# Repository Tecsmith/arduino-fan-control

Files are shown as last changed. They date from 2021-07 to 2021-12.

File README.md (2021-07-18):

# Qwiic Fan Control Module

- This is the **EAGLE** *PCB* design project
- For the **Arduino** *code* library please see [Tecsmith](https://github.com/Tecsmith)/[Tecsmith_AMC6821](https://github.com/Tecsmith/Tecsmith_AMC6821)

AMC6821 based Fan Control Module with Qwiic connectors for integration into 3.3V MCU projects.

| &#8505; | URL |
|---:|-----|
| Project website | [tecsmith.github.io/arduino-fan-control](https://tecsmith.github.io/arduino-fan-control/) |
| Quick link | [`c1k.it/amc6`](http://c1k.it/amc6) |
| Github EAGLE-CAD Source | https://github.com/Tecsmith/arduino-fan-control/tree/master/EAGLE |
| Github PlatformIO Source | https://github.com/Tecsmith/arduino-fan-control/tree/master/PlatformIO |

## About

Thermal control is often arbitrarily implemented in electronics projects – adoption of fans for heat management is often done without consideration for power consumption or acoustic noise.

Leveraging the Texas Instruments AMC6821 chip, this module adds an intelligent temperature monitor and pulse-width modulation (PWM) fan controller to a fan. It is designed for noise-sensitive or power-sensitive applications that require active system cooling. Using a PWM signal, this device simultaneously drives a fan, monitors remote sensor diode temperatures, and measures/controls the fan speed so that it operates with minimal acoustic noise at the lowest possible speed.

This project is an Open Source Hardware (OSH) project and is based on [SparkFun's Qwiic](https://www.sparkfun.com/qwiic) I<sup>2</sup>C connectors and can be integrated into many 3.3V based MCU's.

## AMC6821
### Intelligent temperature monitor and pulse-width modulation fan controller

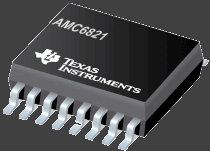
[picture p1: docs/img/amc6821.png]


The AMC6821 is an intelligent temperature monitor and pulse-width modulation (PWM) fan controller. It is designed for noise-sensitive or power-sensitive applications that require active system cooling. Using a low-frequency or a high-frequency PWM signal, this device can simultaneously drive a fan, monitor remote sensor diode temperatures, and measure and control the fan speed so that it operates with minimal acoustic noise at the lowest possible speed.

The AMC6821 has four fan control modes: *Auto Temperature-Fan* mode, *Software-RPM* mode, *Software-DCY* mode, and *Maximum fast-speed calculated control* mode.  Each mode controls the fan speed by changing the duty cycle of a PWM output.

- <u>**Auto Temperature-Fan**</u> mode is an intelligent, closed-loop control that optimizes fan speed according to user-defined parameters. This mode allows the AMC6821 to run as a stand-alone device without CPU intervention; the fan can continue to be controlled (based on temperature measurements) even if the CPU or system locks up.

- <u>**Software-RPM**</u> mode is a second closed-loop control. In this mode, the AMC6821 adjusts the PWM output to maintain a consistent fan speed at a user-specified target value; that is, the device functions as a fan speed regulator. Software-RPM mode can also be used to allow the AMC6821 to operate as a stand-alone device.

- <u>**Software-DCY**</u> mode is the third mode and is open-loop. In Software-DCY mode, the PWM duty cycle is set directly by the value written to the device.

- <u>**Maximum fast-speed calculated control**</u> mode.

The AMC6821 also has a programmable `SMBALERT` output to indicate error conditions and a dedicated `FAN-FAULT` output to indicate fan failure. The `THERM` pin is a fail-safe output for over-temperature conditions that can be used to throttle a CPU clock. Additionally, the `OVR` pin indicates the over-temperature limit as well. All of the alarm thresholds are set through the device registers. The AMC6821 is available in a QSOP-16 package.

## Project Features

- Designed to be an inline series add-on for existing fan implementations.
- Can be powered from 12V and/or 5V power sources. _(Dependant on Fan required operational voltage.)_
- Support most fan types, 5V~ and 12V
  * 4-wire _(Tachometer + PWM)_
  * 3-wire _(Tachometer Sensor)~_
  * 3-wire _(Locked Rotor Sensor)~_
  * 2-wire~
- Can be run as standalone module.
- Can be chained for up to 9 fans, depending on I<sup>2</sup>C addresses set at A0 and A1 pins.
- Both Qwiic and generic I<sup>2</sup>C headers for communication with 3.3V based MCU boards.

> *~ = with add-on MOSFET*

----------
<p align="center" style="color:#069">&#9733;</p>

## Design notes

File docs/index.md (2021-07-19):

# Qwiic Fan Control Module

AMC6821 based Fan Control Module with Qwiic connectors for integration into 3.3V MCU projects.

GitHub repository at [Tecsmith/arduino-fan-control](https://github.com/Tecsmith/arduino-fan-control)

## Features / Specifications

This project contains 2 PCB boards:
* AMC6821 Breakout Board, *allowing intergration via I<sup>2</sup>C to:*
  * [ESP-01 dev board](https://github.com/Tecsmith/arduino-esp-01-dev-board),
  * [Pro-Micro screw terminal board](https://github.com/Tecsmith/arduino-pro-micro-screw-terminal),
  * [Wemos D1 Mini screw terminal board](https://github.com/Tecsmith/arduino-wemos-d1-screw-terminal), and
  * Many other MCU boards from your favorite suppliers, like:
    * [SparkFun](https://www.sparkfun.com/search/results?term=qwiic) Qwiic *[Niwot, Colorado, USA]*
    * [AdaFruit](https://www.adafruit.com/?q=STEMMA+QT) STEMMA QT *[NYC, New York, USA]*
    * [Smart Prototyping](https://www.smart-prototyping.com/index.php?route=product/search&search=qwiic) *[Hong Kong & Shenzhen, China]*
    * [Core Electronics](https://core-electronics.com.au/search/?q=piicodev) PiicoDev *[Hunter Valley, Australia]*
* Fan Host Board, *supporting:*
  * The above [AMC6821 Breakout Board](#), and
  * the [Adafruit EMC2101 Breakout Board](https://www.adafruit.com/product/4808)

### AMC6821 Breakout Board

- Host for [Texas Instruments AMC6821](https://www.ti.com/lit/gpn/amc6821) Intelligent Temperature Monitor and PWM Fan Controller
- Integrates into other 3.3V based MCUs (via Qwiic / STEMMA QT connectors) 
- I<sup>2</sup>C breakout pins (SCL, SDA, 3V3, GND)
  * on board 2.2KΩ pullups, disable by cutting jumpers
- AMC6821 breakout pins (PWM, TACH, <u>FAN-FAULT</u> and <u>SMBALERT</u>. <u>OVR</u> and <u>THERM</u> are also available.)
- Power LED (green)
- 2x Qwiic connector (works with SparkFun's [Qwiic Connect System](https://www.sparkfun.com/qwiic), or Adafruit's [STEMMA QT](https://www.adafruit.com/?q=stemma+qt))
- Supports 2x PWM Modes (via Jumper)
- Supports 9x I<sup>2</sup>C Addresses (via Jumper)
- Includes an on board Temperature sensor
  * can be cut out for remote installation (use rotary cutter along break line)

### Fan Host Board

- Powered from 12V + 5V power supply
  * or just 12V with optional 12V-to-5V ("7805" IC or Pololu 5V Step-Down) regulator
  * or just 5V for 5V fans
- Supports most industry FAN types
  - Molex 4-wire `KK-254-47053-1000` connector
    * 12V PWM, 4-wire, with Tachometer & PWM control
    * 12V, 3-wire, with Tachometer
    * 12V, 3-wire, with Rotor-Lock
    * 12V, 2-wire
  - JST 2-wire connector
    * 5V, 2-wire

----------

## On board jumpers

### AMC6821 Breakout Board

#### JP0 & JP1 - _{A0 & A1}_ - I<sup>2</sup>C Address Selector

| A0 / JP0 | A1 / JP1 |  7-bit  | Hex  | Address |
|:---:|:---:|:---:|:---:|:---|
| GND | GND | 0011000 | `0x18` | 24 *&#9734;* |
| 3V3 | GND | 0011001 | `0x19` | 25 |
|  *N/C~*  | GND | 0011010 | `0x1A` | 26 |
| GND | 3V3 | 1001100 | `0x4C` | 76 |
| 3V3 | 3V3 | 1001101 | `0x4D` | 77 |
|  *N/C~*  | 3V3 | 1001110 | `0x4E` | 78 |
| GND |  *N/C~*  | 0101100 | `0x2C` | 44 |
| 3V3 |  *N/C~*  | 0101001 | `0x2D` | 45 |
|  *N/C~*  |  *N/C~*  | 0101110 | `0x2E` | 46 |

<sub>&#9734; = default setting</sub><br>
<sub>*~* = Not connected</sub>

#### JP2 - _{PWM/M}_ - PWM Mode *(for Frequency selection)*

|  JP2 | PWM Mode |
|:---:|:---|
|  GND | High Frequency range, 1kHz to 40kHz *&#9734; <sup>(25kHz)</sup>* |
|  3V3 | Low Frequency range, 10Hz to 94Hz |

- *Actual PWM Frequency depends on Fan Characteristics Register, bits 3-5*

#### JP3 - _{I2C P/U}_ - I<sup>2</sup>C Pullups Enable

| JP3 | I<sup>2</sup>C Pullups |
|:---:|:---|
| Both connected | 2.2KΩ pull-ups *&#9734;* |
| Both cut | No pull-ups |

- *I<sup>2</sup>C Bus should have at least one set of pullups.*

#### LED (JP4) - Power LED

| LED (JP4) | LED function |
|:---:|:---|
| Tied | LED active to show power state *&#9734;* |
| Cut | Power LED disabled |

### Fan Host Board

The AMC6821 fan controllers has a voltage range on the TACH and PWM pins of -0.3Vdc to 6.5Vdc.  

&#9888; **Do not connect 12Vdc lines to the IC pins.**

#### TACH Control cluster

For the AMC6821 *(and also the EMC2101)* the TACH *(tachometer)* reading is done on the TACH or SENSE pin of the fan.  Most fans operate by grounding this pin once or twice per revolution - thus requiring a pull-up resistor.

##### 12V Fans

For 12V Fans a voltage divider array of resistors *(made up of R2, R3 & R4)* ensure that the TACH pin on the IC is near the 3V range, and the SENS pin on the fan is in the 7V range.

<figure>
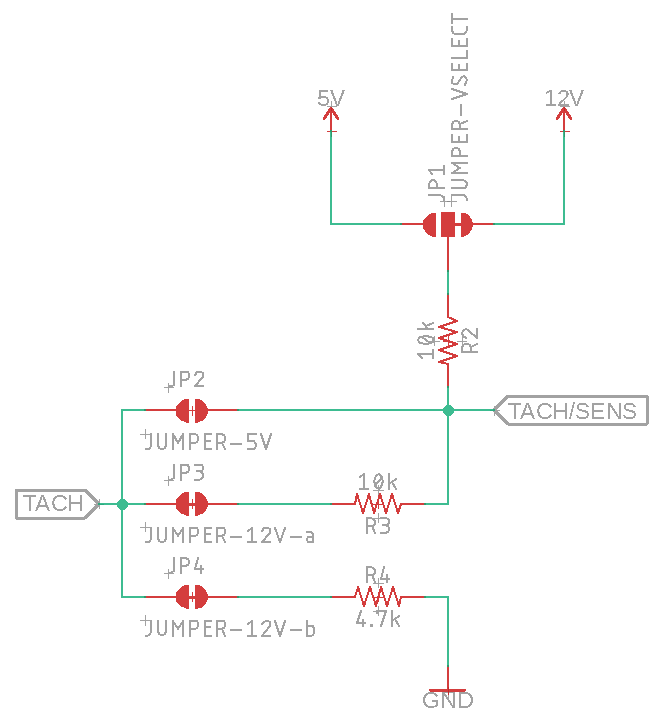
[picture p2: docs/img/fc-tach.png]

<figcaption>TACH circuit with J1 (to 12V), J3 & J4 providing a voltage divider</figcaption>
</figure>

##### 5V Fans

For 5V Fans only a pull-up resistor is required *(R2)*.
* JP2 must be soldered together,
* JP1 must have the 12V trace cut, and the 5V side soldered to center, *and*
* JP3 & JP4 must both be cut

##### TACH Control Cluster

In summary:

| Jumper  | for 12V Fans | for 5V fans |
|:---:|:---:|:---:|
| JP1 | bound to 12V &#9734; | bound to 5V |
| JP2 | cut &#9734; | bound |
| JP3 | bound &#9734; | cut |
| JP4 | bound &#9734; | cut |

#### PWM Control cluster

Fan speed control is managed by the PWM signal from the AMC6821 *(and also the EMC2101)*.  This pin should always be pulled up to the reference voltage of the IC *(not the fan!)*.

> &#8505; &nbsp; The board does ***not*** provide a 3.3Vdc line.  This is sourced from the daughter board GND pin.

<figure>
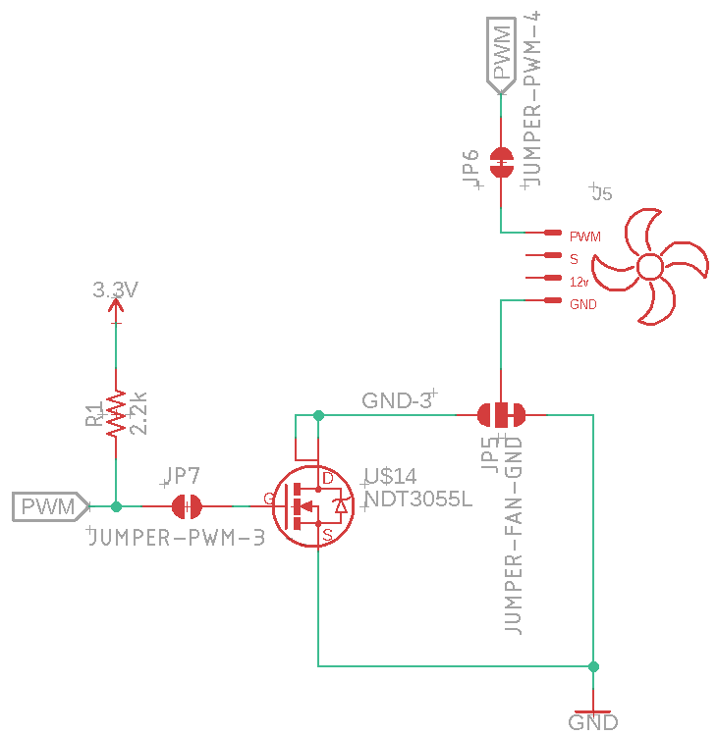
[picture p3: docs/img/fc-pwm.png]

<figcaption>An N-Channel MOSFET provides PWM fan speed control for 3-, or 2- pin fans</figcaption>
</figure>

##### For 4-pin Fans

4-pin fans have a the fourth pin providing PWM signal to the fan internals.  This is pin is enabled by default via the bound trace on JP6.

##### For 2-, and 3-pin Fans

2-, and 3-pin fans do not regulate speed internally, so a N-Channel MOSFET is used to provide low-frequency PWM control to the Ground side of the fan *(avoiding the problems experienced in linear control at lower voltages)*.

To activate the MOSFET driver JP7 must be bound *(and JP6 cut to prevent PWM to fan signal)*.

##### PWM Control cluster

In summary:

| Jumper  | for 4-pin Fans | for 5V fans |
|:---:|:---:|:---:|
| JP5 | bound "to GND" &#9734; | bound "to MFET" |
| JP6 | bound &#9734; | cut |
| JP7 | cut &#9734; | bound |

----------

## Manufacturing

> *I have not sent these for production yet. Want to make sure the thing works on a proto-board first. I'll update this page when done.*

### AMC6821 Breakout Board

* Schematic print:              [`amc6821-breakout-v3.0.pdf`](amc6821-breakout-v3.0.pdf)
* Schematic source (EAGLE CAD): [`amc6821-breakout-v3.0.sch`](https://github.com/Tecsmith/arduino-fan-control/blob/master/EAGLE/amc6821-breakout-v3.0.sch)
* PCB design (EAGLE CAD):       [`amc6821-breakout-v3.0.brd`](https://github.com/Tecsmith/arduino-fan-control/blob/master/EAGLE/amc6821-breakout-v3.0.brd)

--

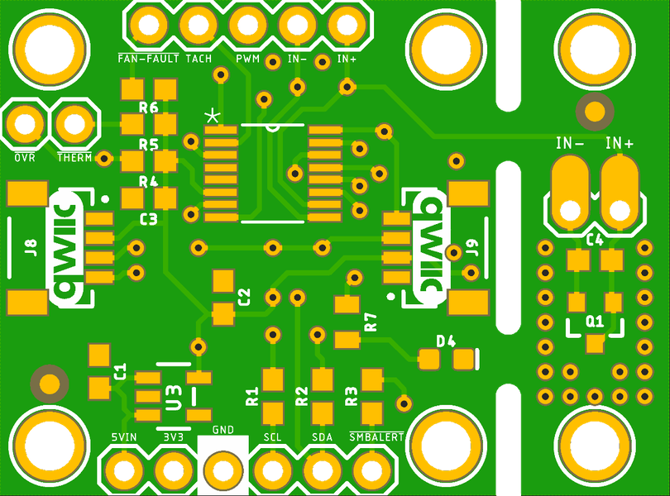
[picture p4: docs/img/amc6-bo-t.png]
<figure><figcaption>Top</figcaption></figure>
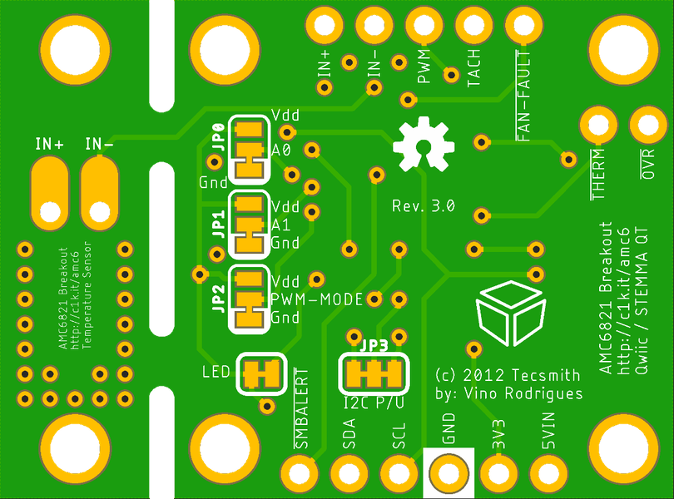
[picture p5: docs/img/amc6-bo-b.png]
<figure><figcaption>Bottom</figcaption></figure>

### Fan Host Board

* Schematic print:              [`fan-host-board-v1.0`](fan-host-board-v1.0.pdf)
* Schematic source (EAGLE CAD): [`fan-host-board-v1.0.sch`](https://github.com/Tecsmith/arduino-fan-control/blob/master/EAGLE/fan-host-board-v1.0.sch)
* PCB design (EAGLE CAD):       [`fan-host-board-v1.0.brd`](https://github.com/Tecsmith/arduino-fan-control/blob/master/EAGLE/fan-host-board-v1.0.brd)

--

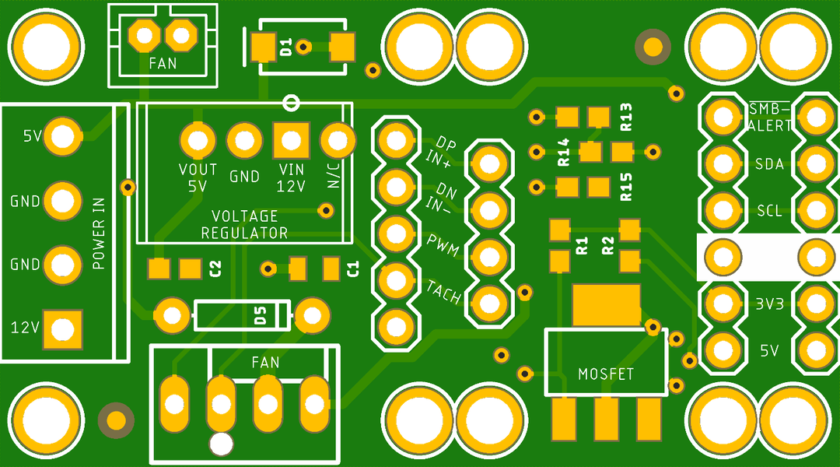
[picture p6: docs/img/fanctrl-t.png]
<figure><figcaption>Top</figcaption></figure>
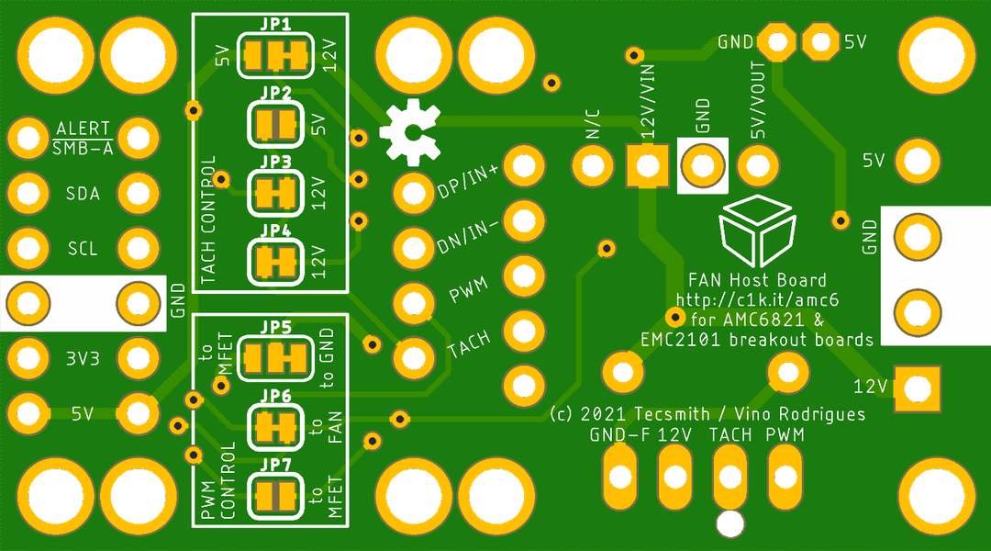
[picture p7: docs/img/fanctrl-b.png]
<figure><figcaption>Bottom</figcaption></figure>

----------

## Source Code

Currently under development ... refer to:

* PlatfromIO examples: [Tecsmith/arduino-fan-control/PlatformIO](https://github.com/Tecsmith/arduino-fan-control/tree/master/PlatformIO)
* AMC6821 Library: [Tecsmith/Tecsmith_AMC6821](https://github.com/Tecsmith/Tecsmith_AMC6821)

----------
<p align="center" style="color:#069">★</p>

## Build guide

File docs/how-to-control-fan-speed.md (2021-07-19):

# Why and How to Control Fan Speed for Cooling Electronic Equipment
***by Mary Burke***<br>
*February 2004*

> Original publication at [AnalogDialogue / analog.com](https://www.analog.com/en/analog-dialogue/articles/how-to-control-fan-speed.html)<br>
> [Download PDF](https://www.analog.com/media/en/analog-dialogue/volume-38/number-1/articles/how-to-control-fan-speed.pdf)

## Introduction

Interest has been growing in integrated circuits for controlling the speed of cooling fans in personal computers and other electronic equipment. Compact electrical fans are cheap and have been used for cooling electronic equipment for more than half a century. However, in recent years, the technology of using these fans has evolved significantly. This article will describe how and why this evolution has taken place and will suggest some useful approaches for the designer.

## Heat Generation and Removal

The trend in electronics, particularly consumer electronics, is towards smaller products with enhanced combinations of features. Consequently, lots of electronic components are being shoehorned into very small form factors. An obvious example is the notebook PC. Thin and “Lite,” notebook PCs have shrunk significantly, yet their processing power has been maintained or increased. Other examples of this trend include projection systems and set-top boxes. What these systems all have in common, besides significantly smaller—and still decreasing—size, is that the amount of heat they must dissipate does not decrease; often it increases! In the notebook PC, much of the heat is generated by the processor; in the projector, most of the heat is generated by the light source. This heat needs to be removed quietly and efficiently.

The quietest way to remove heat is with passive components such as heat sinks and heat pipes. However, these have proved insufficient in many popular consumer electronics products—and they are also somewhat expensive. A good alternative is active cooling, introducing a fan into the system to generate airflow around the chassis and the heat-generating components, efficiently removing heat from the system. A fan is a source of noise, however. It is also an additional source of power consumption in the system—a very important consideration if power is to be supplied by a battery. The fan is also one more mechanical component in the system, not an ideal solution from a reliability standpoint.

*Speed control* — one way to answer some of these objections to the use of a fan—can have these advantages:

1. running a fan slower reduces the noise it emits,
2. running a fan slower can reduce the power it consumes,
3. running a fan slower increases its reliability and lifetime.

There are many different types of fans and ways of controlling them. We will discuss here various fan types and the advantages and disadvantages of control methods in use today. One way to classify fans is as:

1. 2-wire fans
2. 3-wire fans 
3. 4-wire fans.

The methods of fan control to be discussed here include:

1. no fan control
2. on/off control
3. linear (continuous dc) control
4. low-frequency pulse-width modulation (PWM)
5. high-frequency fan control.

## Fan Types

A 2-wire fan has power and ground terminals. A 3-wire fan has power, ground, and a tachometric (“tach”) output, which provides a signal with frequency proportional to speed. A 4-wire fan has power, ground, a tach output, and a PWM-drive input. PWM, in brief, uses the relative width of pulses in a train of on-off pulses to adjust the level of power applied to the motor.

A 2-wire fan is controlled by adjusting either the dc voltage or pulse width in low-frequency PWM. However, with only two wires, a tach signal is not readily available. This means that there is no indication as to how fast the fan is running—or indeed, if it is running at all. This form of speed control is open-loop.

A 3-wire fan can be controlled using the same kind of drive as for 2-wire fans—variable dc or low-frequency PWM. The difference between 2-wire fans and 3-wire fans is the availability of feedback from the fan for closed-loop speed control. The tach signal indicates whether the fan is running and its rate of speed.

The tach signal, when driven by a dc voltage, has a square-wave output closely resembling the “ideal tach” in Figure 1. It is always valid, since power is continuously applied to the fan. With low- frequency PWM, however, the tach signal is valid only when power is applied to the fan—that is, during the on phase of the pulse. When the PWM drive is switched to the off phase, the fan’s internal tach signal-generation circuitry is also off. Because the tach output is typically from an open drain, it will float high when the PWM drive is off, as shown in Figure 1. Thus, while the ideal tach is representative of the actual speed of the fan, the PWM drive in effect “chops” the tach signal output and may produce erroneous readings.

<figure>
  
  <figcaption>Figure 1. Tachometer-output waveform in 3-wire fans—ideal, and under PWM control.</figcaption>
</figure>

In order to be sure of a correct fan speed reading under PWM control, it is necessary to periodically switch the fan on long enough to get a complete tach cycle. This feature is implemented in a number of Analog Devices fan controllers, such as the ADM1031 and the ADT7460.

In addition to the power, ground, and tach signal, 4-wire fans have a PWM input, which is used to control the speed of the fan. Instead of switching the power to the entire fan on and off, only the power to the drive coils is switched, making the tach information available continuously. Switching the coils on and off generates some commutation noise. Driving the coils at rates greater than 20 kHz moves the noise outside of the audible range, so typical PWM fan-drive signals use a rather high frequency (>20 kHz). Another advantage of 4-wire fans is that the fan speed can be controlled at speeds as low as 10% of the fan’s full speed. Figure 2 shows the differences between 3-wire and 4-wire fan circuits.

<figure>
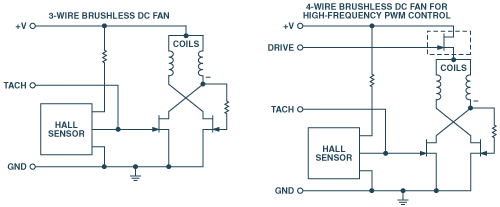
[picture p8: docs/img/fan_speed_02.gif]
  
  <figcaption>Figure 2. 3- and 4-wire fans.</figcaption>
</figure>

## Fan Control

No control: The simplest method of fan control is not to use any at all; just run a fan of appropriate capacity at full speed 100% of the time. The main advantages of this are guaranteed fail-safe cooling and a very simple external circuit. However, because the fan is always switched on, its lifetime is reduced and it uses a constant amount of power—even when cooling is not needed. Also, its incessant noise is likely to be annoying.

On/off control: The next simplest method of fan control is thermostatic, or on/off control. This method is also very easy to implement. The fan is switched on only when cooling is needed, and it is switched off for the remainder of the time. The user needs to set the conditions under which cooling is needed—typically when the temperature exceeds a preset threshold.

The Analog Devices ADM1032 is an ideal sensor for on/off fan control using a temperature setpoint. It has a comparator that produces a THERM output—one that is normally high but switches low when the temperature exceeds a programmable threshold. It automatically switches back to high when the temperature drops a preset amount below the THERM Limit. The advantage of this programmable hysteresis is that the fan does not continually switch on/off when the temperature is close to the threshold. Figure 3 is an example of a circuit using the ADM1032.

<figure>
  
  <figcaption>Figure 3. Example of an on/off control circuit.</figcaption>
</figure>

The disadvantage of on/off control is that it is very limited. When a fan is switched on, it immediately spins up to its full speed in an audible and annoying manner. Because humans soon become somewhat accustomed to the sound of the fan, its switching off is also very noticeable. (It can be compared to the refrigerator in your kitchen. You didn’t notice the noise it was making until it switched off.) So from an acoustic perspective, on/off control is far from optimal.

**Linear control:** At the next level of fan control, linear control, the voltage applied to the fan is variable. For lower speed (less cooling and quieter operation) the voltage is decreased, and for higher speed it is increased. The relationship has limitations. Consider, for example, a 12-V fan (rated maximum voltage). Such a fan may require at least 7 V to start spinning. When it does start spinning, it will probably spin at about half its full speed with 7 V applied. Because of the need to overcome inertia, the voltage required to start a fan is higher than the voltage required to keep it spinning. So as the voltage applied to the fan is reduced, it may spin at slower speeds until, say, 4 V, at which point it will stall. These values will differ, from manufacturer to manufacturer, from model to model, and even from fan to fan.

The Analog Devices ADM1028 linear fan-control IC has a programmable output and just about every feature that might be needed in fan control, including the ability to interface accurately to the temperature-sensing diode provided on chips, such as microprocessors, that account for most of the dissipation in a system. (The purpose of the diode is to provide a rapid indication of critical junction temperatures, avoiding all the thermal lags inherent in a system. It permits immediate initiation of cooling, based on a rise in chip temperature.) In order to keep the power used by the ADM1028 at a minimum, it operates on supply voltages from 3.0 V to 5.5 V, with +2.5-V full scale output.

5-V fans allow only a limited range of speed control, since their start-up voltage is close to their 5-V full speed level. But the ADM1028 can be used with 12-V fans by employing a simple step-up booster amplifier with a circuit such as that shown in Figure 4.

<figure>
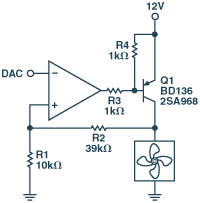
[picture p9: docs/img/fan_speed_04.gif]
  
  <figcaption>Figure 4. Boost circuit for driving a 12-V fan, using the output from the linear fan-control ADM1028’s DAC.</figcaption>
</figure>

The principal advantage of linear control is that it is quiet. However, as we have noted, the speed-control range is limited. For example, a 12-V fan with a control voltage range from 7 V to 12 V could be running at half speed at 7 V. The situation is even worse with a 5-V fan. Typically, 5-V fans will require that 3.5 V or 4 V be applied to get them started, but at that voltage they will be running at close to full speed, with a very limited range of speed control. But running at 12 V, using circuits such as that shown in Figure 4, is far from optimum from an efficiency perspective. That is because the boost transistor dissipates a relatively large amount of power (when the fan is operating at 8 V, the 4-V drop across the transistor is not very efficient). The external circuit required is also relatively expensive.

**PWM Control:** The prevalent method currently used for controlling fan speed in PCs is low-frequency PWM control. In this approach, the voltage applied to the fan is always either zero or full-scale—avoiding the problems experienced in linear control at lower voltages. Figure 5 shows a typical drive circuit used with PWM output from the ADT7460 thermal voltage controller.

<figure>
  
  <figcaption>Figure 5. A low-frequency PWM fan-drive circuit.</figcaption>
</figure>

The principal advantage of this drive method is that it is simple, inexpensive, and very efficient, since the fan is either fully on or fully off.

A disadvantage is that the tach information is chopped by the PWM drive signal, since power is not always applied to the fan. The tach information can be retrieved using a technique called pulse stretching—switching the fan on long enough to gather the tach information (with a possible increase of audible noise). Figure 6 shows a case of pulse stretching.

<figure>
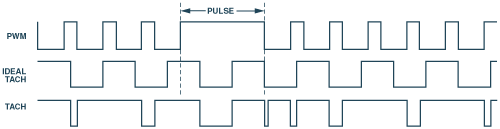
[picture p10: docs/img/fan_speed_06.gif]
  
  <figcaption>Figure 6. Pulse stretching to gather tach information.</figcaption>
</figure>

Another disadvantage of low-frequency PWM is commutation noise. With the fan coils continuously switched on and off, audible noise may be present. To deal with this noise, the newest Analog Devices fan controllers are designed to drive the fan at a frequency of 22.5 kHz, which is outside the audible range. The external control circuit is simpler with high-frequency PWM, but it can only be used with 4-wire fans. Although these fans are relatively new to the market, they are rapidly becoming more popular. Figure 7 depicts the circuit used for high-frequency PWM.

<figure>
  
  <figcaption>Figure 7. Circuit for driving a fan with high-frequency PWM.</figcaption>
</figure>

The PWM signal drives the fan directly; the drive FET is integrated inside the fan. Reducing the external component count, this approach makes the external circuit much simpler. Since the PWM drive signal is applied directly to the coils of the fan, the fan’s electronics are always powered on, and the tach signal is always available. This eliminates the need for pulse stretching—and the noise it can produce. The commutation noise is also eliminated, or reduced significantly, since the coils are being switched with a frequency outside the audible range.

## Summary

From the standpoints of acoustic noise, reliability, and power efficiency, the most preferable method of fan control is the use of high-frequency (>20 kHz) PWM drive.

Besides eliminating the need for noisy pulse stretching and the commutation noise associated with low-frequency PWM, it has a much wider control range than linear control. With high- frequency PWM, the fan can be run at speeds as low as 10% of full speed, while the same fan may only run at a minimum of 50% of full speed using linear control. It is more energy efficient, because the fan is always either fully on or fully off. (With the FET either off or in saturation, its dissipation is very low, eliminating the significant losses in the transistor in the linear case.) It is quieter than always-on or on/off control, since the fan can run at lower speeds—that can be varied gradually. Finally, running the fan slower also improves its lifetime, increasing system reliability.

| Control Method | Advantages | Disadvantages |
|:---:|:---|:---|
| On/Off | Inexpensive | Worst acoustic performance—fan is always running. |
| Linear | Most quiet | Expensive circuit <br> Inefficient—loss of power in the amplifier circuit |
| Low-Frequency PWM | Efficient <br> Wide speed-control range when measuring speed | Fan commutation noise <br> Pulse stretching required |
| High-Frequency PWM | Efficient <br> Good acoustics, almost as good as linear. <br> Inexpensive external circuit <br> Wide speed-control range |  Must use 4-wire fans |

<p align="center" style="color:#069">★</p>

> &copy; Analog Dialogue 38-02, February (2004), accessed from https://www.analog.com/en/analog-dialogue/articles/how-to-control-fan-speed.html, accessed 19 July 202<br>
> PDF available from https://www.analog.com/media/en/analog-dialogue/volume-38/number-1/articles/how-to-control-fan-speed.pdf

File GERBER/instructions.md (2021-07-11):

Instructions
============

See this Tutorial: https://www.youtube.com/watch?v=y3GviDr0o1s

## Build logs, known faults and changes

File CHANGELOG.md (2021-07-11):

# Changelog
All notable changes to this project will be documented in this file.

The format is based on [Keep a Changelog](https://keepachangelog.com/en/1.0.0/),
and this project adheres to [Semantic Versioning](https://semver.org/spec/v2.0.0.html).

[[[[[ **This project is in WIP state.** ]]]]]

## [Unreleased]

### Added

- Rebuild of PlatformIO examples

### Removed

- Sub projects removed (and added to their own GitHub projects)
  * [arduino-esp-01-dev-board](https://github.com/Tecsmith/arduino-esp-01-dev-board)
  * [arduino-pro-micro-screw-terminal](https://github.com/Tecsmith/arduino-pro-micro-screw-terminal)
  * [arduino-wemos-d1-screw-terminal](https://github.com/Tecsmith/arduino-wemos-d1-screw-terminal)
  * arduino-emc2101 *(deleted)*

### Changed

- Arduino examples renamed.  These will stay, but not be maintained or added on as PlatformIO is the preferred environment.

## [2.3.0] - 2020-12-17

### Added

- Initial AMC6820 and SMBus libraries
- WIP PlatformIO code to test IC integration

### Changed

- Realized that JP2 = A0 and JP3 = A1 could lead to confusion, renamed all JP's (with J0 = A0 & J1 = A1)
- Created expanded solder pads on Optional Temp. Sensor to allow for horizontal cable soldering.
- Moved Qwiic connectors up by 25mil to allow better clearance of mounting screws.
- Issue identified with JLCPCB validation
    + C7 (Optional Temp. Sensor capacitor) was the incorrect footprint, changed from 0402 to 0805.  This is a breaking error, however, since sensor is optional will not impact development of firmware.
    + Q2, Q3, Q4 (Red LED inversion transistors) were the incorrect footprint.  Non-breaking.  Changed to SOT23-3. Moved the route airwires to accommodate.

## [2.2.0] - 2020-12-05

### Changed

- Fix for the Qwiic connector being oriented the wrong way

## [2.1.0] - ?

- Unreleased

## [2.0.0] - 2020-11-02

### Added
- Initial release (and first production run with [JLCPCB](https://jlcpcb.com/))

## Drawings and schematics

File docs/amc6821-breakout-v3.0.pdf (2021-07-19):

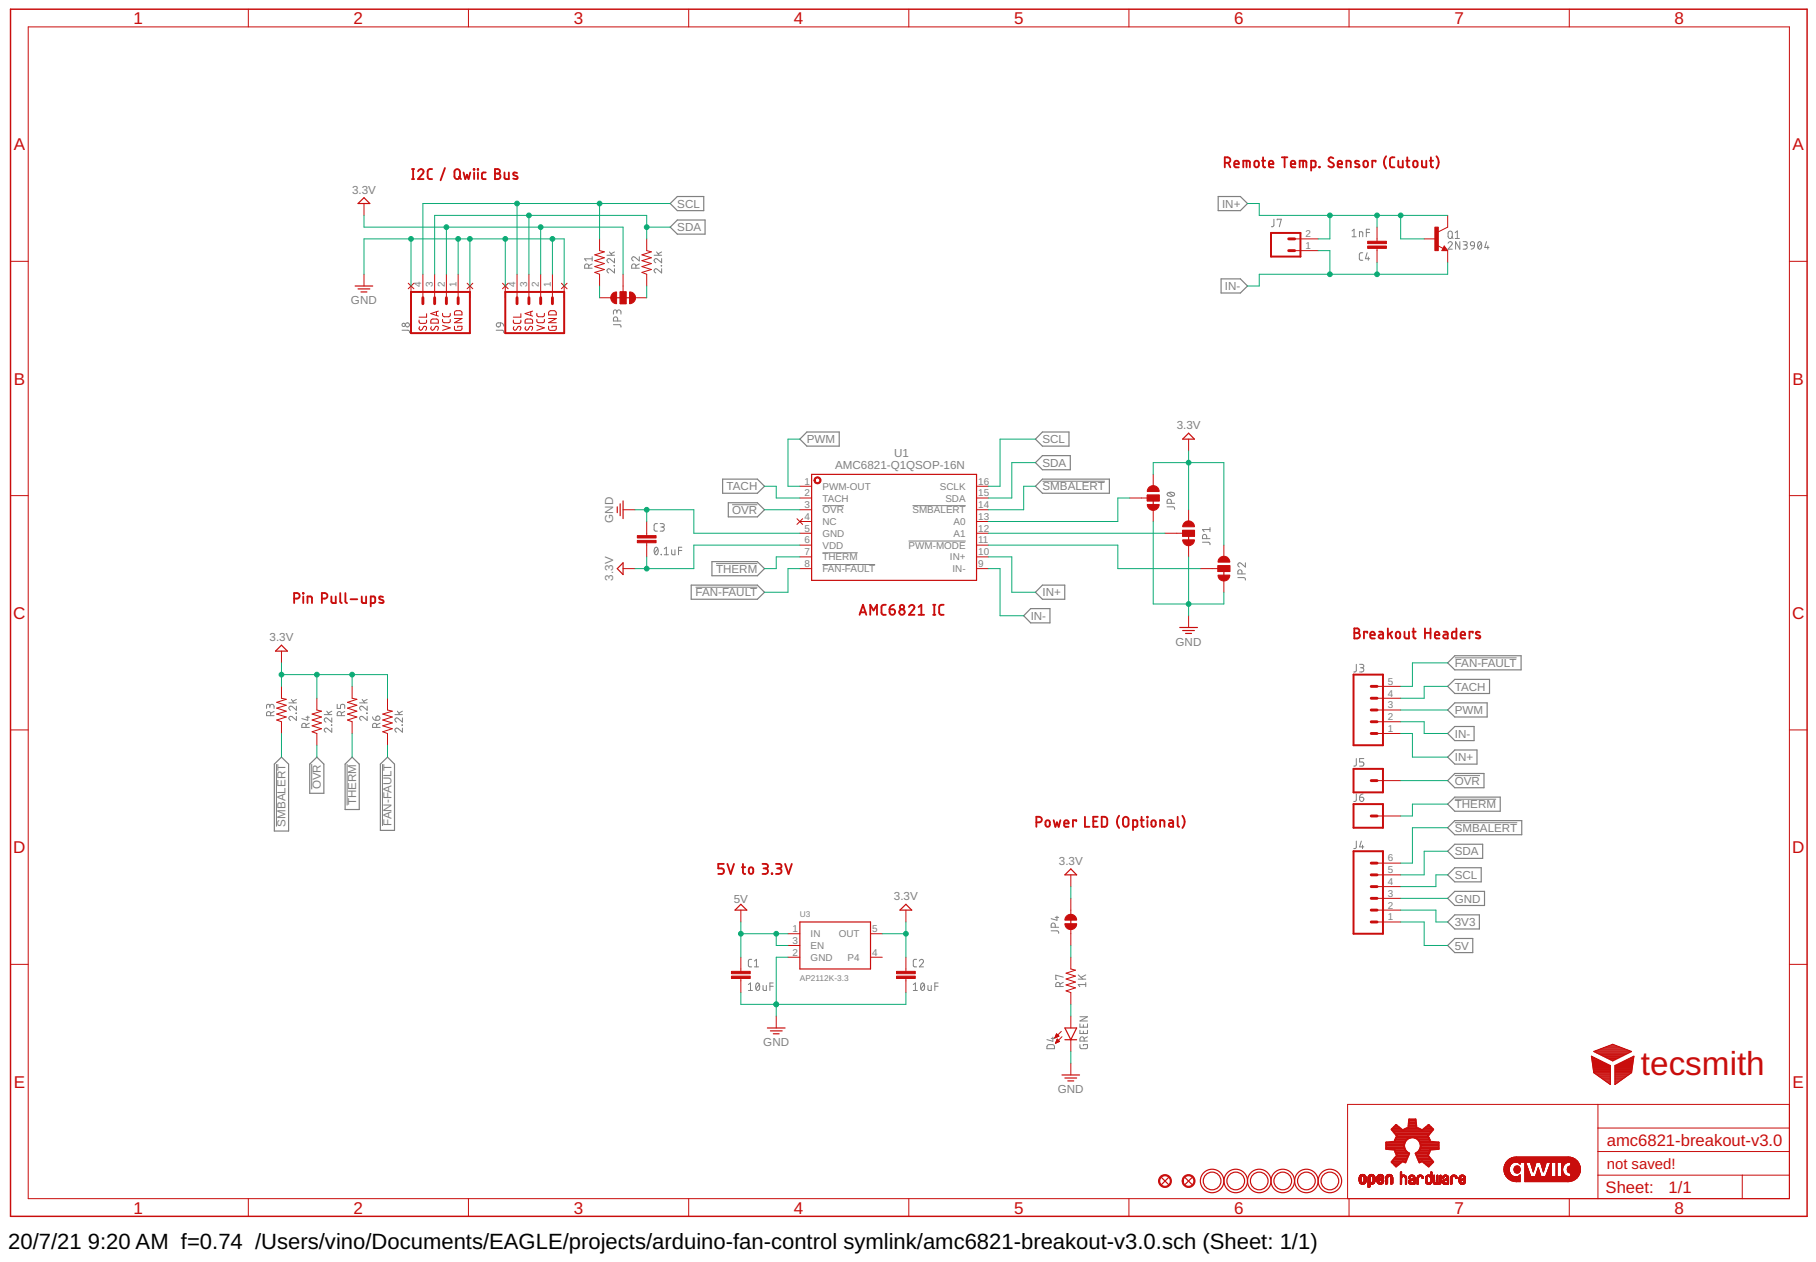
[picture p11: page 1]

20/7/21 9:20 AM f=0.74 /Users/vino/Documents/EAGLE/projects/arduino-fan-control symlink/amc6821-breakout-v3.0.sch (Sheet: 1/1)

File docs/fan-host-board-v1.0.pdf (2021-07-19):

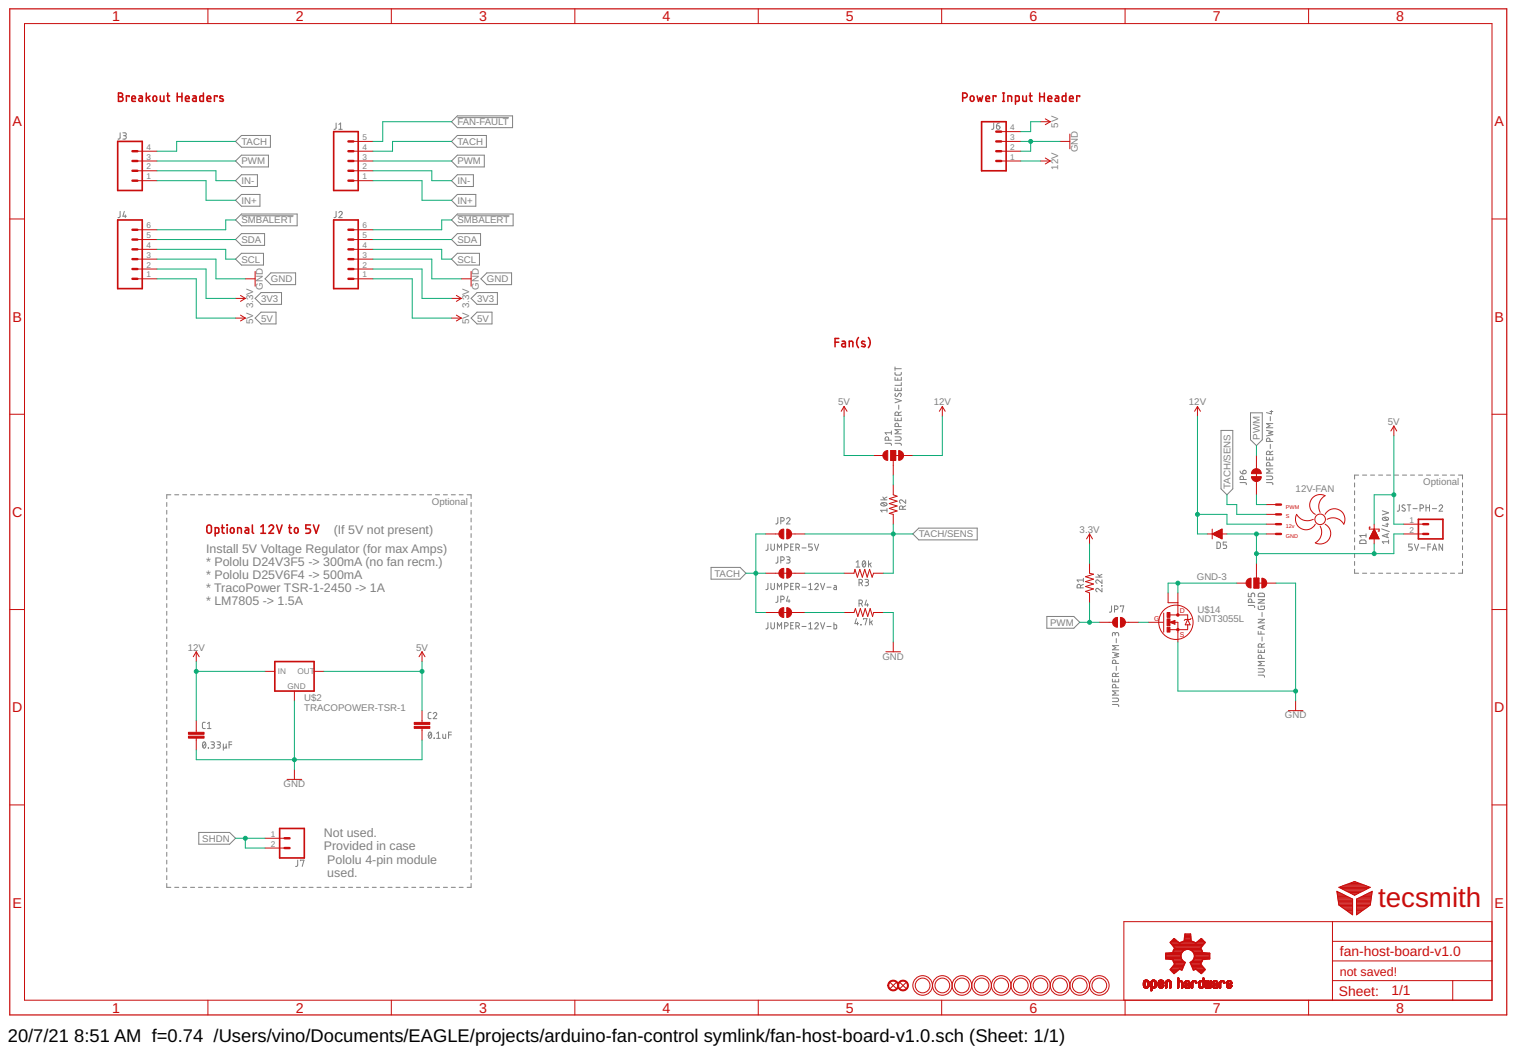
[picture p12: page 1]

Install 5V Voltage Regulator (for max Amps) * Pololu D24V3F5 -> 300mA (no fan recm.) * Pololu D25V6F4 -> 500mA

Not used. Provided in case Pololu 4-pin module

20/7/21 8:51 AM f=0.74 /Users/vino/Documents/EAGLE/projects/arduino-fan-control symlink/fan-host-board-v1.0.sch (Sheet: 1/1)

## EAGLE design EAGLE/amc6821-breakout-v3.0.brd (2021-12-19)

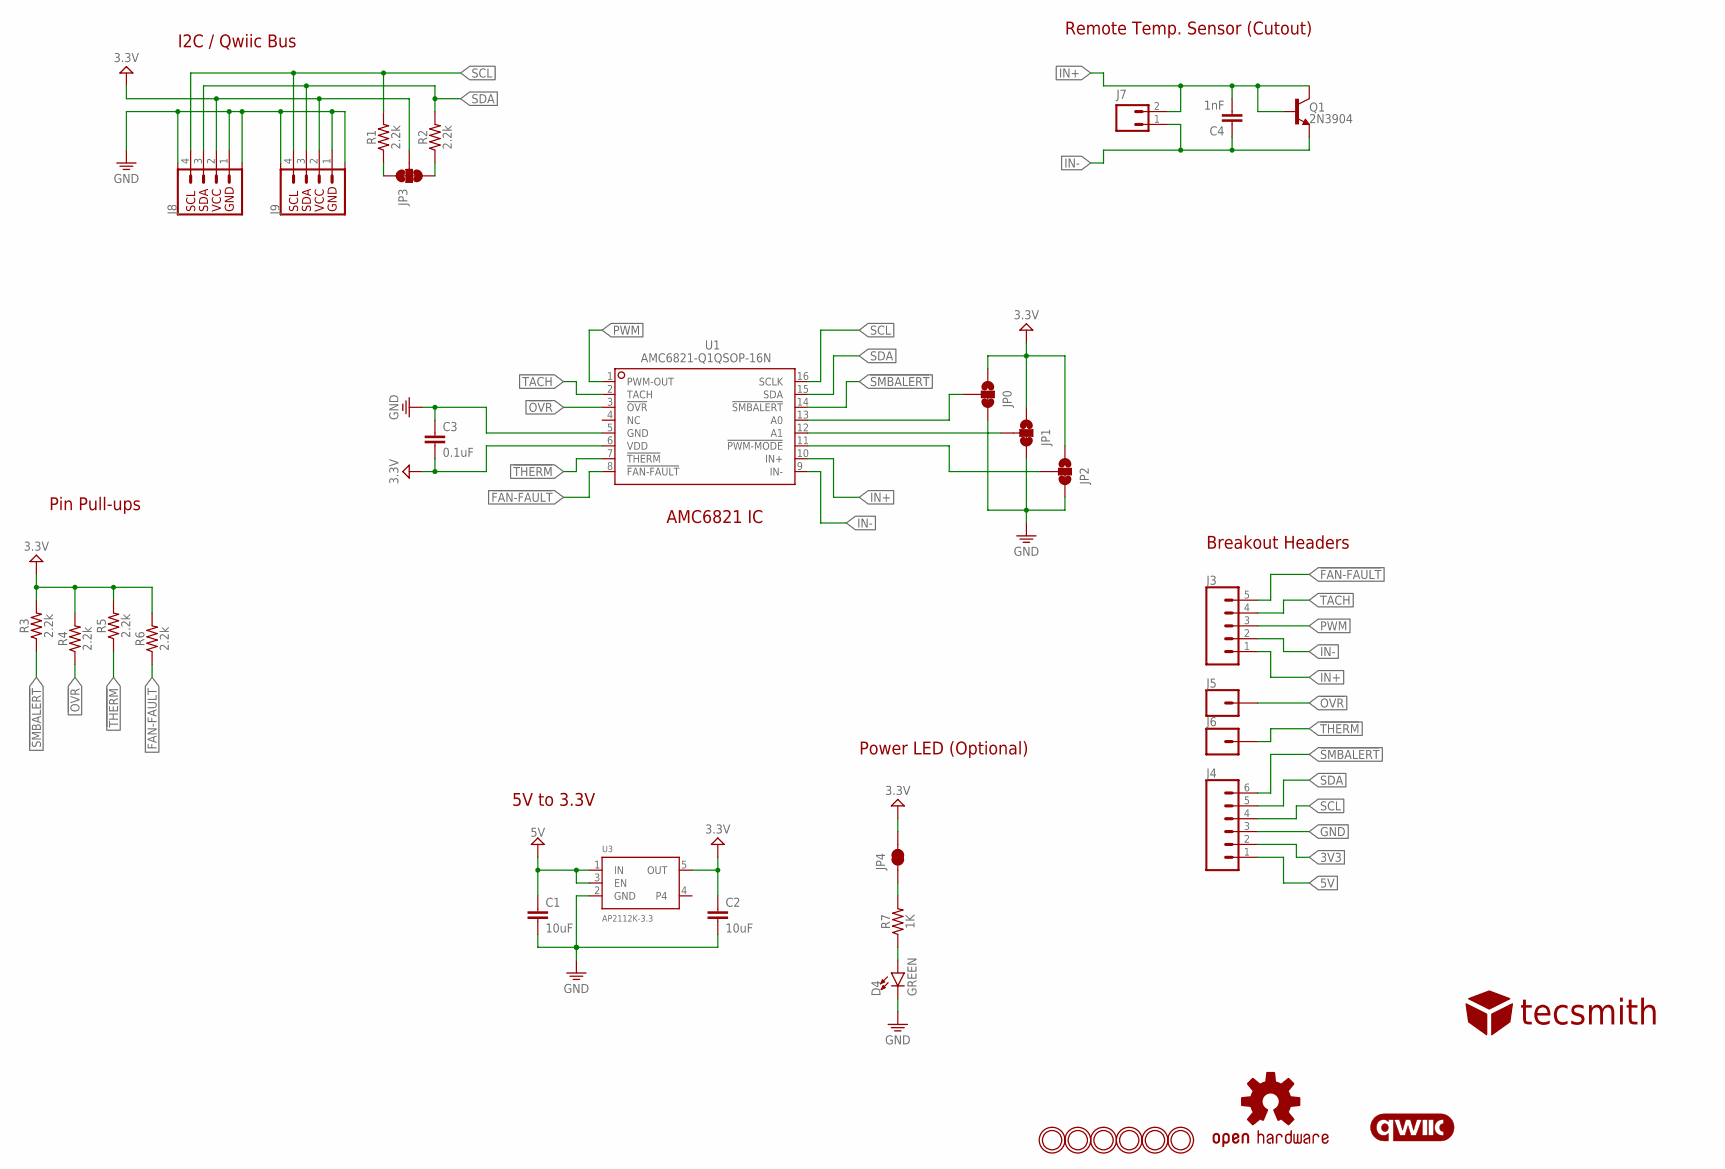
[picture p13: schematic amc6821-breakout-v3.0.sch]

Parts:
C1, C2: 10uF; 0603
C3: 0.1uF; 0603
C4: 1nF; 0603
D4: GREEN; LED-0603
J3: CONN_05; 1X05
J4: CONN_06SILK_FEMALE_PTH; 1X06
J5, J6: CONN_01; 1X01
J7: CONN_02; 1X02-LONG
J8, J9: QWIIC_RIGHT_ANGLE; JST04_1MM_RA
JP0, JP1, JP2: JUMPER-SMT_3_1-NC_TRACE_SILK; SMT-JUMPER_3_1-NC_TRACE_SILK
JP3: JUMPER-SMT_3_2-NC_TRACE_SILK; SMT-JUMPER_3_2-NC_TRACE_SILK
JP4: JUMPER-SMT_2_NC_TRACE_SILK; SMT-JUMPER_2_NC_TRACE_SILK
LOGO1: OSHW-LOGOS; OSHW-LOGO-S
LOGO2: QWIIC_LOGO_6MM; QWIIC_6MM
Q1: 2N3904; SOT23-3
R1, R2, R3, R4, R5, R6: 2.2k; 0603
R7: 1K; 0805
U1: AMC6821-Q1QSOP-16N; QSOP-16N
U3: AP2112K-3.3; SOT23-5
U$1: TECSMITH-LOGO
U$4, U$5, U$7, U$8, U$9, U$10: MOUNTINGHOLE2.5; MOUNTINGHOLE_2.5_PLATED

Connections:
3V3: C2.1, C3.2, J4.2, J8.2, J9.2, JP0.1, JP1.1, JP2.1, JP3.2, JP4.2, R3.2, R4.2, R5.2, R6.2, U1.6 (VDD), U3.5 (OUT)
5V: C1.1, J4.1, U3.1 (IN), U3.3 (EN)
!FAN-FAULT: J3.5, R6.1, U1.8 (!FAN-FAULT)
!OVR: J5.1, R4.1, U1.3 (!OVR)
!SMBALERT: J4.6, R3.1, U1.14 (!SMBALERT)
!THERM: J6.1, R5.1, U1.7 (!THERM)
GND: C1.2, C2.2, C3.1, D4.C, J4.3, J8.1, J8.NC1, J8.NC2, J9.1, J9.NC1, J9.NC2, JP0.3, JP1.3, JP2.3, U1.5 (GND), U3.2 (GND)
IN+: C4.2, J3.1, J7.2, Q1.1 (B), Q1.3 (C), U1.10 (IN+)
IN-: C4.1, J3.2, J7.1, Q1.2 (E), U1.9 (IN-)
unnamed: JP0.2, U1.13 (A0)
unnamed: JP3.3, R2.1
unnamed: JP3.1, R1.1
unnamed: JP2.2, U1.11 (!PWM-MODE)
unnamed: JP1.2, U1.12 (A1)
unnamed: D4.A, R7.1
unnamed: JP4.1, R7.2
PWM: J3.3, U1.1 (PWM-OUT)
SCL: J4.4, J8.4, J9.4, R1.2, U1.16 (SCLK)
SDA: J4.5, J8.3, J9.3, R2.2, U1.15 (SDA)
TACH: J3.4, U1.2 (TACH)

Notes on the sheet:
I2C / Qwiic Bus
Breakout Headers
5V to 3.3V
AMC6821 IC
Remote Temp. Sensor (Cutout)
Pin Pull-ups
Power LED (Optional)

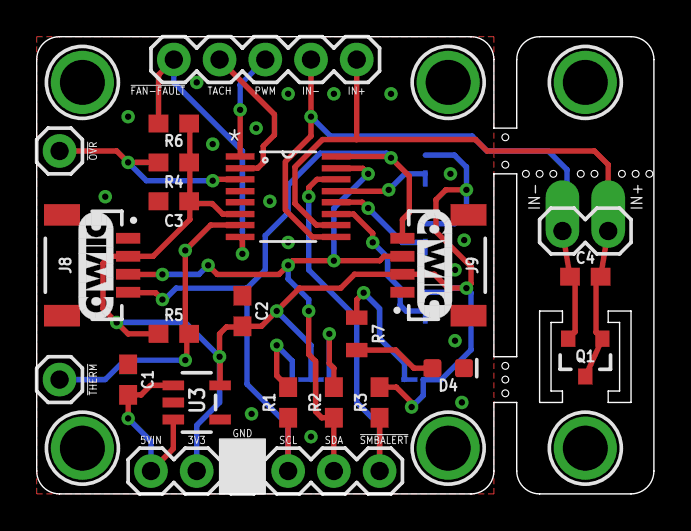
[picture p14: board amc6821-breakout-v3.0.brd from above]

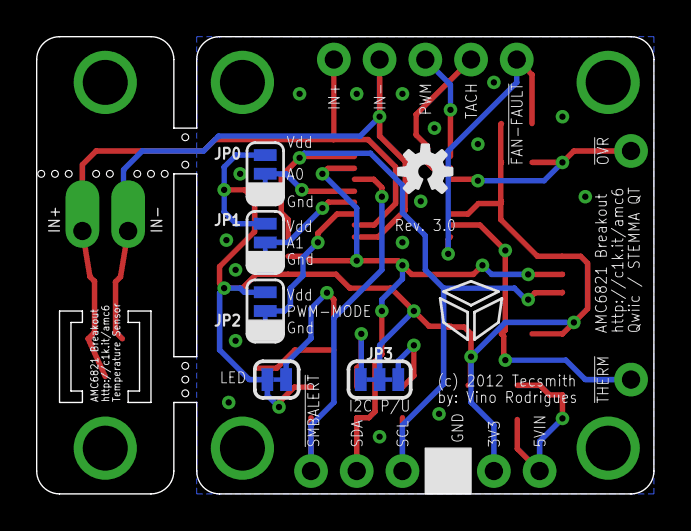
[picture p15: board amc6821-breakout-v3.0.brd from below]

Board: 2 copper layers, 34.3 x 25.4 mm, 37 parts (7 on the bottom side), 20 nets.

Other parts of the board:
LOGO3: QWIIC_LOGO_6MM; QWIIC_6MM

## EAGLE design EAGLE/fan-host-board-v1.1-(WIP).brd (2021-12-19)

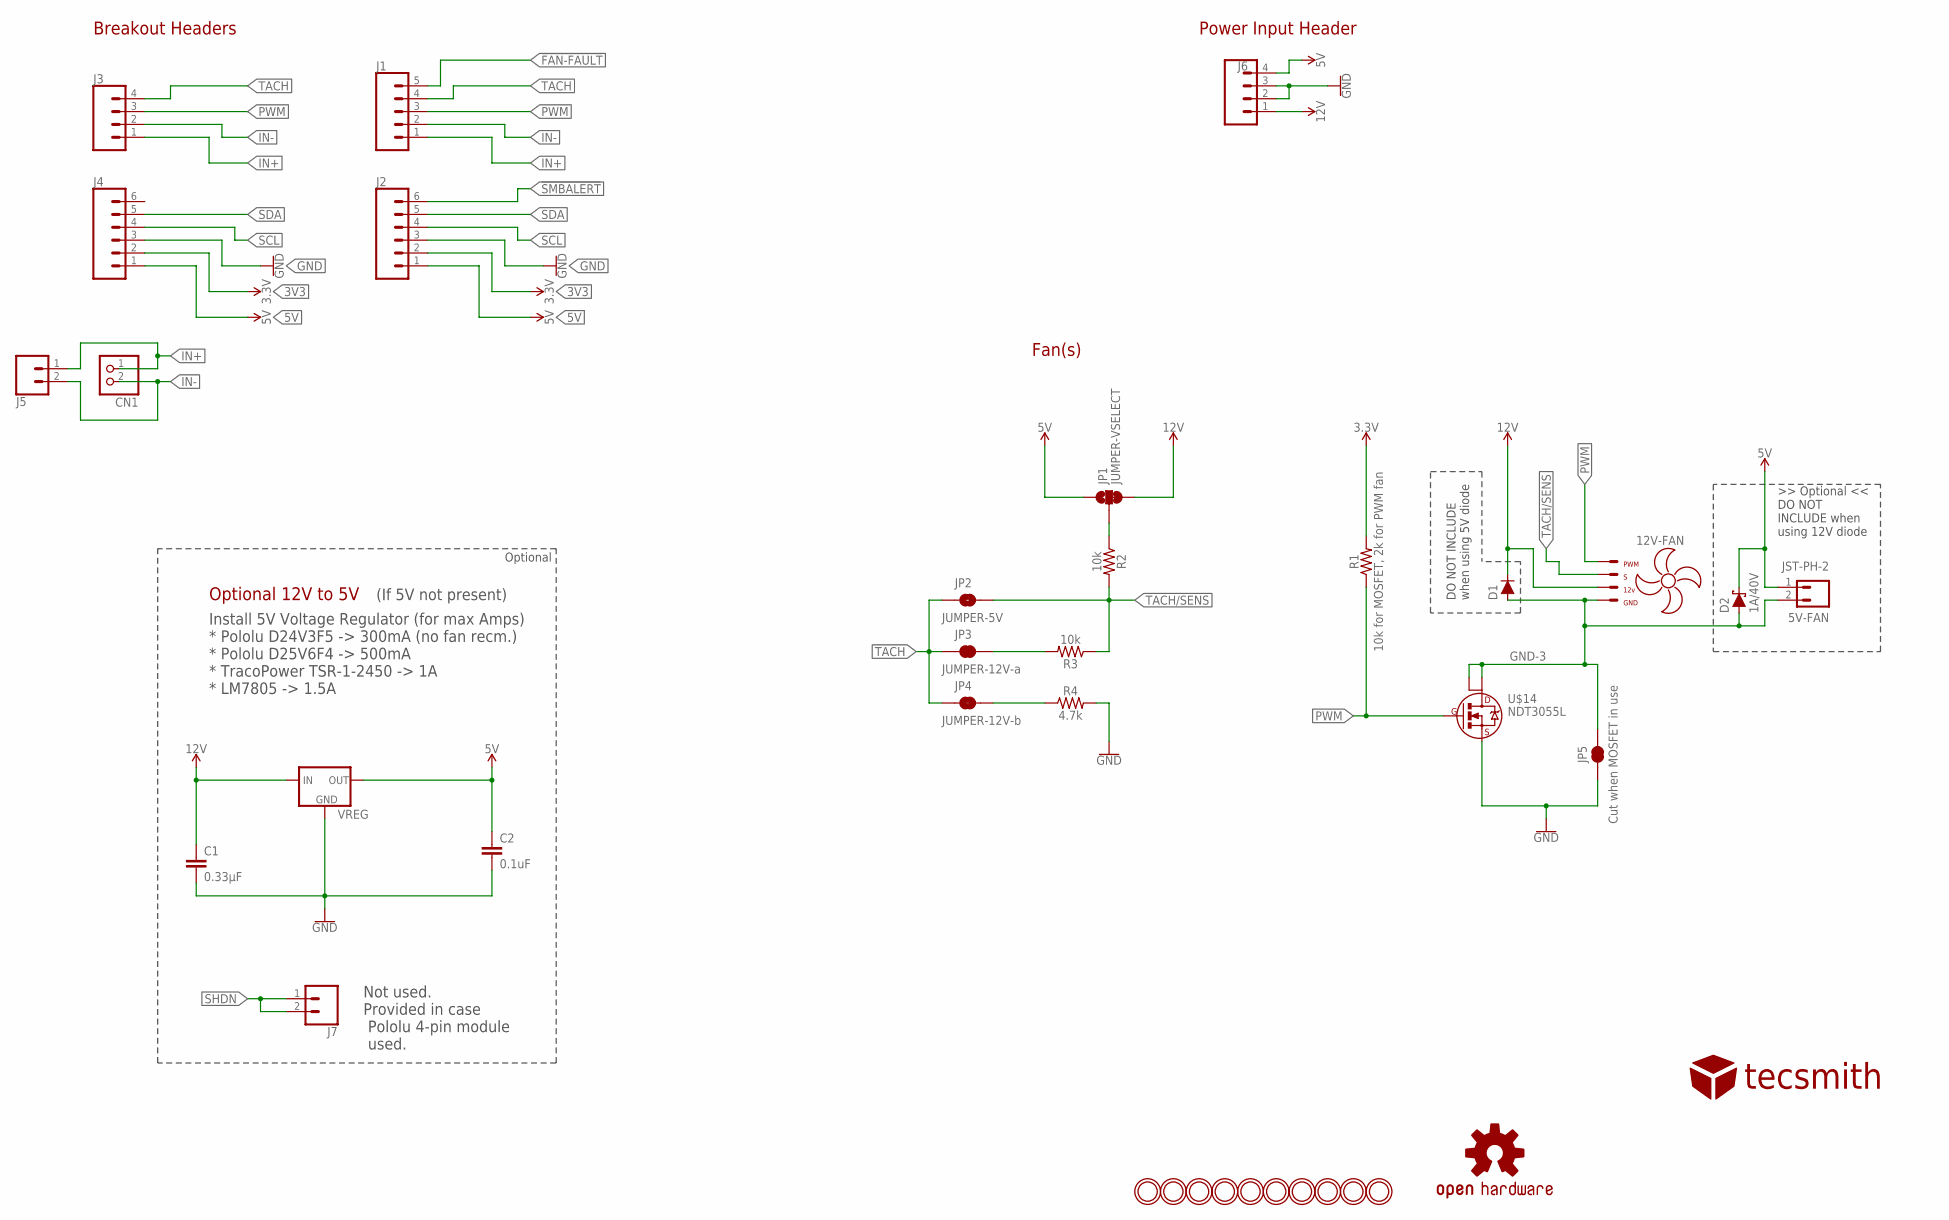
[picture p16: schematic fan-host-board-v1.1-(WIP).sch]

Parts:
5V-FAN: JST-PH-2; JST-PH2
12V-FAN: KK-254-4KK-254; MOLEX_47053-1000
C1: 0.33µF; 0805
C2: 0.1uF; 0603
CN1: JST_2PIN-THM; JST-PH-2-THM
D1: 200mA/100V; DIODE-1N4148
D2: 1A/40V; SMA-DIODE
J1: CONN_05; 1X05
J2, J4: CONN_06SILK_FEMALE_PTH; 1X06
J3: CONN_04PTH; 1X04
J5: CONN_02PTH3; 1X02_LONGPADS
J6: CONN_04SCREW; SCREWTERMINAL-3.5MM-4
J7: CONN_021X02_NO_SILK; 1X02_NO_SILK
JP1: JUMPER-VSELECT; SMT-JUMPER_3_1-NC_TRACE_SILK
JP2: JUMPER-5V; SMT-JUMPER_2_NO_SILK
JP3: JUMPER-12V-a; SMT-JUMPER_2_NC_TRACE_SILK
JP4: JUMPER-12V-b; SMT-JUMPER_2_NC_TRACE_SILK
JP5: Cut when MOSFET in use; SMT-JUMPER_2_NC_TRACE_NO-SILK
LOGO1: OSHW-LOGOS; OSHW-LOGO-S
R1: 10k for MOSFET, 2k for PWM fan; 0603
R2, R3: 10k; 0603
R4: 4.7k; 0603
U$1: TECSMITH-LOGO
U$2, U$3, U$4, U$5, U$6, U$7, U$8, U$9, U$10, U$11: MOUNTINGHOLE2.5; MOUNTINGHOLE_2.5_PLATED
U$14: NDT3055L; SOT223
VREG: TRACOPOWER-TSR-1; TRACO-TSR-1

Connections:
3V3: J2.2, J4.2, R1.2
5V: 5V-FAN.1, C2.1, D2.C, J2.1, J4.1, J6.4, JP1.1, VREG.P$+VOUT (OUT)
12V: 12V-FAN.2:+12VDC, C1.1, D1.C, J6.1, JP1.3, VREG.P$+VIN (IN)
!FAN-FAULT: J1.5
!SMBALERT: J2.6
GND: C1.2, C2.2, J2.3, J4.3, J6.2, J6.3, JP5.1, R4.2, U$14.S, VREG.P$GND (GND)
GND-3: 5V-FAN.2, 12V-FAN.1:GND, D1.A, D2.A, JP5.2, U$14.D, U$14.D2
IN+: CN1.1 (2), J1.1, J3.1, J5.1
IN-: CN1.2 (1), J1.2, J3.2, J5.2
unnamed: JP1.2, R2.1
unnamed: JP3.2, R3.2
unnamed: JP4.2, R4.1
PWM: 12V-FAN.4:PWM, J1.3, J3.3, R1.1, U$14.G
SCL: J2.4, J4.4
SDA: J2.5, J4.5
SHDN: J7.1, J7.2
TACH: J1.4, J3.4, JP2.1, JP3.1, JP4.1
TACH/SENS: 12V-FAN.3:TACH, JP2.2, R2.2, R3.1

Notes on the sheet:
Fan(s)
Power Input Header
Optional 12V to 5V
Install 5V Voltage Regulator (for max Amps) * Pololu D24V3F5 -> 300mA (no fan recm.) * Pololu D25V6F4 -> 500mA * TracoPower TSR-1-2450 -> 1A * LM7805 -> 1.5A
Breakout Headers
(If 5V not present)
Optional
Not used. Provided in case Pololu 4-pin module used.
DO NOT INCLUDE when using 5V diode

Board: 2 copper layers, 37 parts (6 on the bottom side), 16 nets, no tracks yet.

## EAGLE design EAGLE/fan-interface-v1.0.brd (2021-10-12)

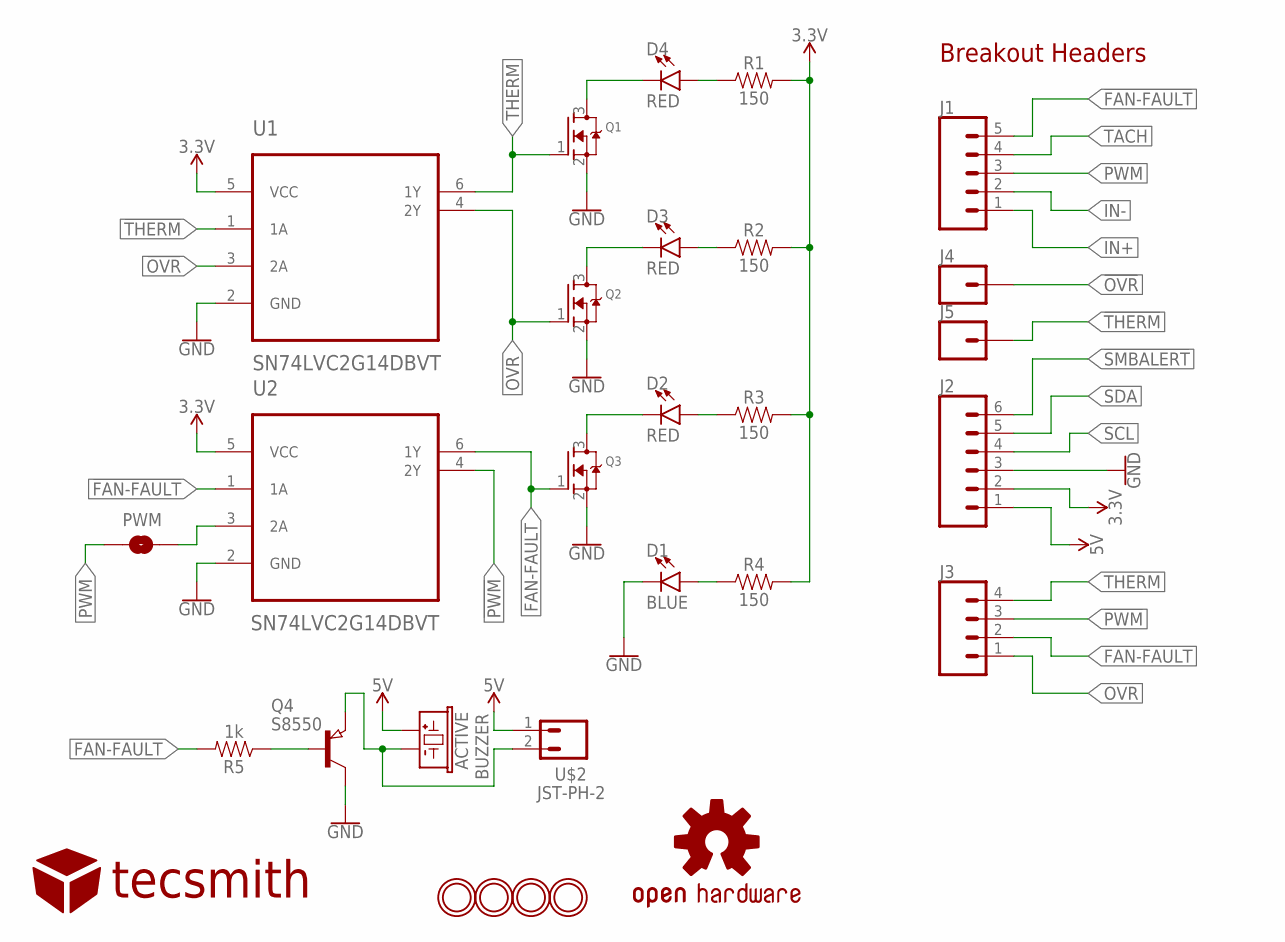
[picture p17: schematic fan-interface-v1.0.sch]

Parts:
ACTIVE: BUZZER; BUZZER-SMD
D1: BLUE; LED-0603
D2, D3, D4: RED; LED-0603
J1: CONN_05; 1X05
J2: CONN_06SILK_FEMALE_PTH; 1X06
J3: CONN_04PTH; 1X04
J4, J5: CONN_01; 1X01
LOGO1: OSHW-LOGOS; OSHW-LOGO-S
PWM: JUMPER-SMT_2_NO_SILK; SMT-JUMPER_2_NO_SILK
Q1, Q2, Q3: MOSFET-NREFLOW; SOT23
Q4: S8550; SOT23
R1, R2, R3, R4: 150; 0603
R5: 1k; 0603
U1, U2: SN74LVC2G14DBVT; SOT95P280X145-6N
U$1: TECSMITH-LOGO
U$2: JST-PH-2; JST-PH2
U$7, U$8, U$9, U$10: MOUNTINGHOLE2.5; MOUNTINGHOLE_2.5_PLATED

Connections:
3.3V: J2.2, R1.2, R2.2, R3.2, R4.2, U1.5 (VCC), U2.5 (VCC)
5V: ACTIVE.+ (1), ACTIVE.+1 (1), J2.1, U$2.1
!FAN-FAULT: J1.5, U2.1 (1A)
!OVR: J4.1, U1.3 (2A)
!PWM: J3.3, U2.4 (2Y)
!SMBALERT: J2.6
!THERM: J5.1, U1.1 (1A)
FAN-FAULT: J3.2, Q3.1 (G), R5.2, U2.6 (1Y)
GND: D1.C, J2.3, Q1.2 (S), Q2.2 (S), Q3.2 (S), Q4.3 (C), U1.2 (GND), U2.2 (GND)
IN+: J1.1
IN-: J1.2
unnamed: D4.C, Q1.3 (D)
unnamed: D4.A, R1.1
unnamed: D3.A, R2.1
unnamed: D3.C, Q2.3 (D)
unnamed: PWM.2, U2.3 (2A)
unnamed: Q4.1 (B), R5.1
unnamed: D2.A, R3.1
unnamed: D2.C, Q3.3 (D)
unnamed: D1.A, R4.1
unnamed: ACTIVE.- (2), ACTIVE.-1 (2), Q4.2 (E), U$2.2
OVR: J3.1, Q2.1 (G), U1.4 (2Y)
PWM: J1.3, PWM.1
SCL: J2.4
SDA: J2.5
TACH: J1.4
THERM: J3.4, Q1.1 (G), U1.6 (1Y)

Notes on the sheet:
Breakout Headers

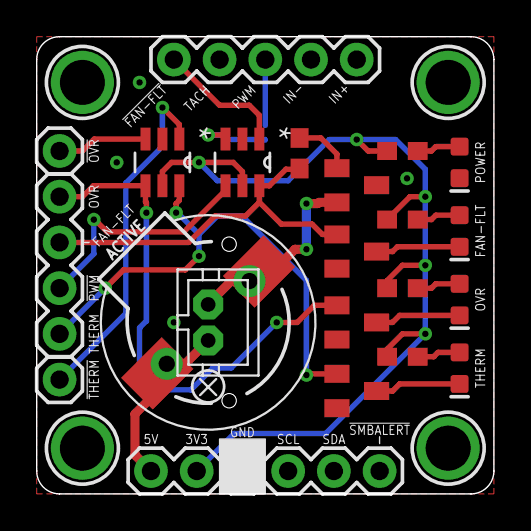
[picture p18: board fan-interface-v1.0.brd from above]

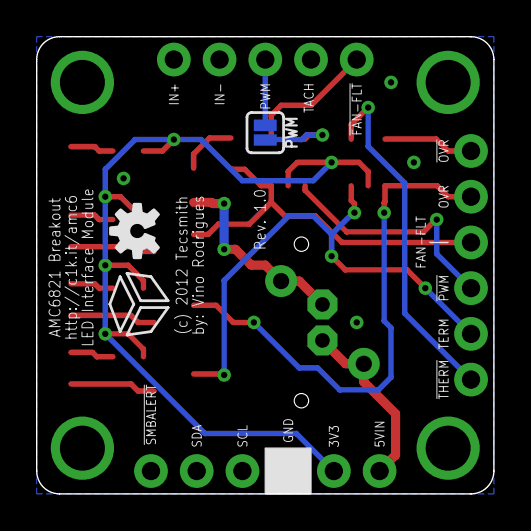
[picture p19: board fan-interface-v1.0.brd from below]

Board: 2 copper layers, 25.4 x 25.4 mm, 29 parts (3 on the bottom side), 21 nets.

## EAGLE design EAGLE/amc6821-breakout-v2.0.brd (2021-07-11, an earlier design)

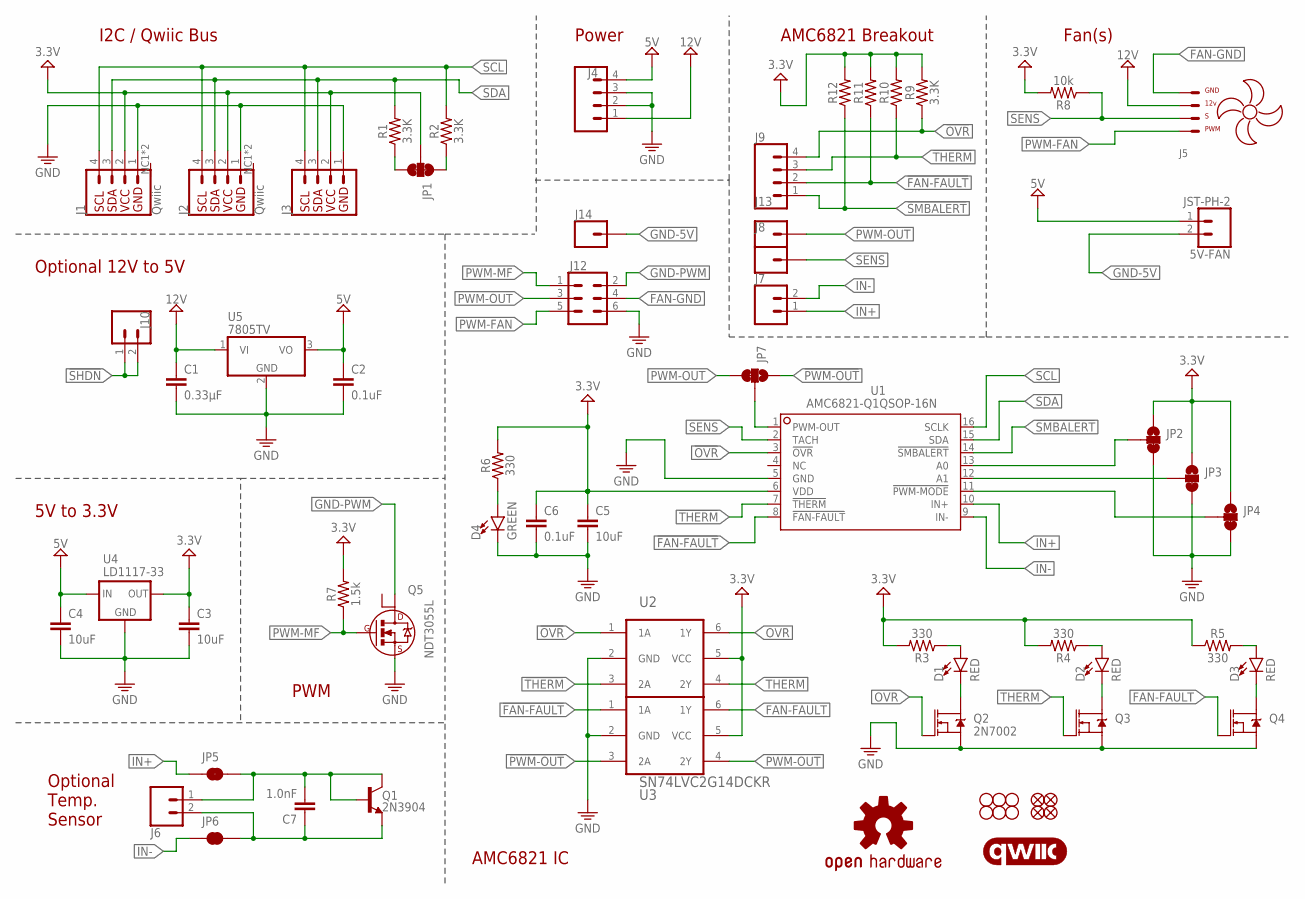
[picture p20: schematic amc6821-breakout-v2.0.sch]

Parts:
5V-FAN: JST-PH-2; JST-PH2
C1: 0.33µF; 0805
C2, C6: 0.1uF; 0603
C3, C4, C5: 10uF; 0603
C7: 1.0nF; 0402-TIGHT
D1, D2, D3: RED; LED-0603
D4: GREEN; LED-0603
FD1, FD2, FD3, FD4: FIDUCIALUFIDUCIAL; FIDUCIAL-MICRO
H1, H2, H3, H4, H5, H6: STAND-OFF
J1, J2: Qwiic; JST04_1MM_VERT
J3: I2C_STANDARD; 1X04
J4: CONN_04SCREW; SCREWTERMINAL-3.5MM-4
J5: KK-254-4KK-254; MOLEX_47053-1000
J6, J7: CONN_02; 1X02
J8, J13, J14: CONN_01; 1X01
J9: CONN_04PTH; 1X04
J10: CONN_021X02_NO_SILK; 1X02_NO_SILK
J12: CONN_03X2NO_SILK; 2X3-NS
JP1: JUMPER-SMT_3_2-NC_TRACE_SILK; SMT-JUMPER_3_2-NC_TRACE_SILK
JP2, JP3, JP4, JP7: JUMPER-SMT_3_1-NC_TRACE_SILK; SMT-JUMPER_3_1-NC_TRACE_SILK
JP5, JP6: JUMPER-SMT_2_NC_TRACE_SILK; SMT-JUMPER_2_NC_TRACE_SILK
LOGO1: OSHW-LOGOS; OSHW-LOGO-S
LOGO2: QWIIC_LOGO_6MM; QWIIC_6MM
Q1: 2N3904; SOT23-3
Q2: 2N7002; SOT323
Q3, Q4: 310mA/60V/1.6Ω; SOT323
Q5: NDT3055L; SOT223
R1, R2, R9, R10, R11, R12: 3.3K; 0805
R3, R4, R5, R6: 330; 0805
R7: 1.5k; 0603
R8: 10k; 0603
U1: AMC6821-Q1QSOP-16N; QSOP-16N
U2, U3: SN74LVC2G14DCKR; SOT65P210X110-6N
U4: LD1117-33; SOT223
U5: 7805TV; TO220V

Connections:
3V3: C3.1, C5.1, C6.1, J1.2, J2.2, J3.2, JP1.2, JP2.1, JP3.1, JP4.1, R3.2, R4.2, R5.1, R6.2, R7.2, R8.2, R9.2, R10.2, R11.2, R12.2, U1.6 (VDD), U2.5 (VCC), U3.5 (VCC), U4.2 (OUT)
5V: 5V-FAN.1, C2.1, C4.1, J4.4, U4.3 (IN), U5.3 (VO)
12V: C1.1, J4.1, J5.2:+12VDC, U5.1 (VI)
!FAN-FAULT: J9.2, R11.1, U1.8 (!FAN-FAULT), U3.1 (1A)
!OVR: J9.4, R9.1, U1.3 (!OVR), U2.1 (1A)
!PWM-OUT: JP7.1, U3.3 (2A)
!SHDN: J10.1, J10.2
!SMBALERT: J9.1, R12.1, U1.14 (!SMBALERT)
!THERM: J9.3, R10.1, U1.7 (!THERM), U2.3 (2A)
FAN-FAULT: Q4.1 (G), U3.6 (1Y)
FAN-GND: J5.1:GND, J12.4
GND: C1.2, C2.2, C3.2, C4.2, C5.2, C6.2, D4.C, J1.1, J2.1, J3.1, J4.2, J4.3, J12.6, JP2.3, JP3.3, JP4.3, Q2.2 (S), Q3.2 (S), Q4.2 (S), Q5.S, U1.5 (GND), U2.2 (GND), U3.2 (GND), U4.1 (GND), U5.2 (GND)
GND-5V: 5V-FAN.2, J14.1
GND-PWM: J12.2, Q5.D
IN+: J7.1, JP5.1, U1.10 (IN+)
IN-: J7.2, JP6.1, U1.9 (IN-)
unnamed: JP2.2, U1.13 (A0)
unnamed: C7.2, J6.1, JP5.2, Q1.1 (B), Q1.3 (C)
unnamed: JP1.3, R1.1
unnamed: JP1.1, R2.1
unnamed: JP4.2, U1.11 (!PWM-MODE)
unnamed: JP3.2, U1.12 (A1)
unnamed: C7.1, J6.2, JP6.2, Q1.2 (E)
unnamed: D4.A, R6.1
unnamed: D3.A, R5.2
unnamed: D3.C, Q4.3 (D)
unnamed: D1.A, R3.1
unnamed: D1.C, Q2.3 (D)
unnamed: D2.C, Q3.3 (D)
unnamed: D2.A, R4.1
unnamed: JP7.2, U1.1 (PWM-OUT)
OVR: Q2.1 (G), U2.6 (1Y)
PWM-FAN: J5.4:PWM, J12.5
PWM-MF: J12.1, Q5.G, R7.1
PWM-OUT: J12.3, J13.1, JP7.3, U3.4 (2Y)
SCL: J1.4, J2.4, J3.4, R2.2, U1.16 (SCLK)
SDA: J1.3, J2.3, J3.3, R1.2, U1.15 (SDA)
SENS: J5.3:TACH, J8.1, R8.1, U1.2 (TACH)
THERM: Q3.1 (G), U2.4 (2Y)

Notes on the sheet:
I2C / Qwiic Bus
Fan(s)
AMC6821 Breakout
Power
Optional 12V to 5V
5V to 3.3V
AMC6821 IC
Optional Temp. Sensor
PWM

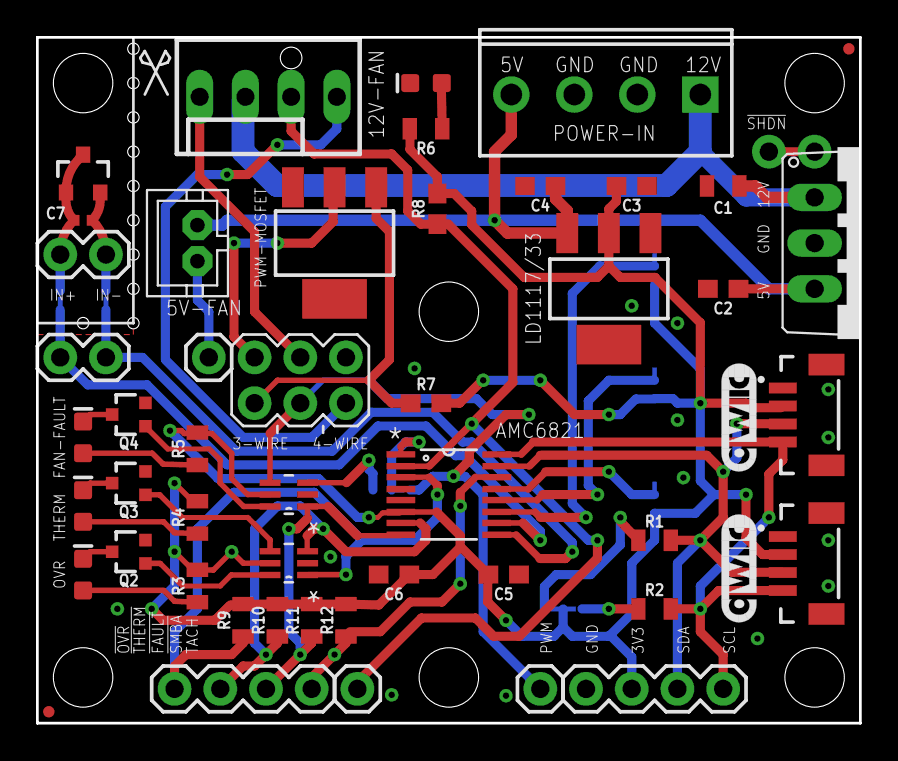
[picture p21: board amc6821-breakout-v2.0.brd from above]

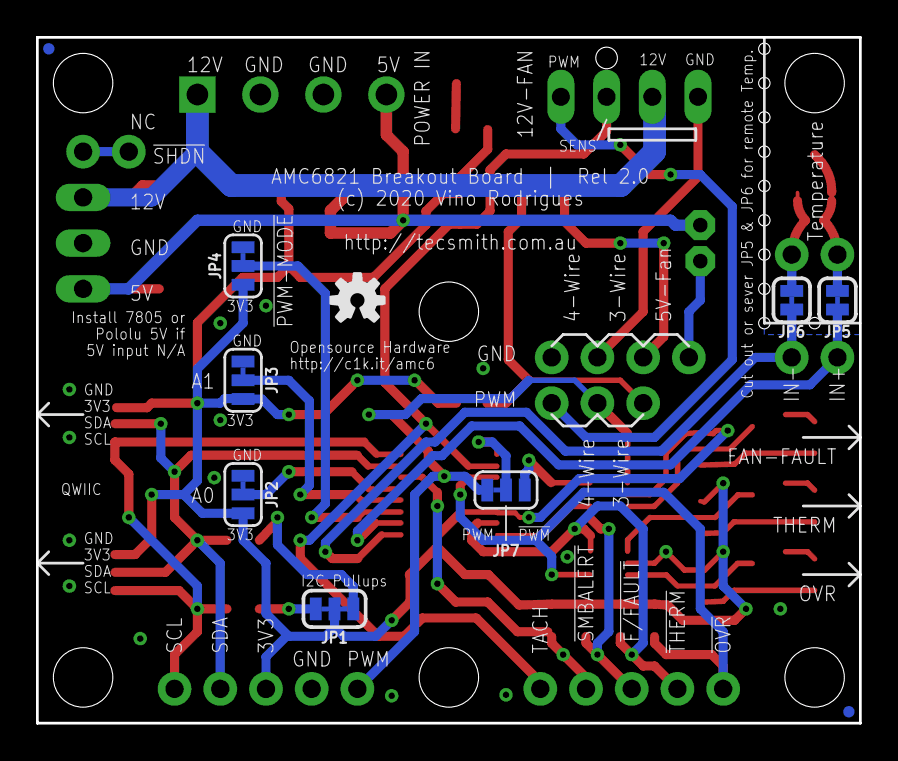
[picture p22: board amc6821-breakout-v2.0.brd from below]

Board: 2 copper layers, 45.7 x 38.1 mm, 67 parts (11 on the bottom side), 39 nets.

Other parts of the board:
LOGO5: QWIIC_LOGO_6MM; QWIIC_6MM

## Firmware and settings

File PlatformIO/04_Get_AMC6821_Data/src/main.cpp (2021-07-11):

#include <Arduino.h>
#include <SPI.h>
#include <Wire.h>
#include <Tecsmith_AMC6821.h>

#ifdef ARDUINO_ESP8266_ESP01
  #define SDA_PIN 0
  #define SCL_PIN 2
#endif

Tecsmith_AMC6821 amc6821;  // instance
byte looplimit;

void phex(int unsigned num, int precision = 2) {
  uint8_t b;
  char tmp[4];

  if ((precision != 2) && (precision != 4)) return;

  if (precision == 4) {
    b = (uint8_t)((num & 0xFF00) >> 8);
    sprintf(tmp, "%02X", b);
    Serial.print(tmp);
  }

  b = (uint8_t)(num & 0x00FF);
  sprintf(tmp, "%02X", b);
  Serial.print(tmp);
}

void p_(const char *a, const int b, const char *c = "") {
  Serial.print(a);
  Serial.print(" = [0x");
  phex(b);
  Serial.print("] <0b");
  for (int x = 7; x >= 0; x--) { Serial.print(bitRead(b, x)); }
  Serial.print("> ");
  Serial.print(b, DEC);
  Serial.print(" ");
  Serial.println(c);
}

void b_(const char *a, const bool b, const char *c = "") {
  Serial.print(a);
  Serial.print(" = ");
  Serial.print(b);
  Serial.print(" ");
  if (b) {
    Serial.print("TRUE");
  } else {
    Serial.print("false");
  }
  Serial.print(" ");
  Serial.println(c);
}


void q_(const char *a, const unsigned int d, const char *c = "") {
  Serial.print(a);
  Serial.print(" = [0x");
  phex(d, 4);
  Serial.print("] <0b");
  for (int x = 15; x >= 0; x--) { Serial.print(bitRead(d, x)); }
  Serial.print("> ");
  Serial.print(d, DEC);
  Serial.print(" ");
  Serial.println(c);
}

void n_(const char *a, const unsigned long d, const char *c = "") {
  Serial.print(a);
  Serial.print(" = ");
  Serial.print(d);
  Serial.print(" ");
  Serial.println(c);
}

// ---------- ! ----------

void setup() {
  // put your setup code here, to run once:

  Serial.begin(57600);
  while (!Serial) delay(10);

  #ifdef ARDUINO_ESP8266_ESP01
  Wire.begin(SDA_PIN, SCL_PIN);
  #else
  Wire.begin();
  #endif

  Serial.println("Tecsmith AMC6821 test!");

  // Try to initialize!
  if (!amc6821.begin()) {
    Serial.println("Failed to find AMC6821 chip");
    while (1) { delay(10); }
  }
  Serial.println("AMC6821 Found!");
  amc6821.start();

  looplimit = 2;
}

void loop() {
  // put your main code here, to run repeatedly:

  int32_t i;

  Serial.println("\n------------------------------------------------------------");

  p_("             Device ID", amc6821.getDeviceID());
  p_("            Company ID", amc6821.getCompanyID());
  p_("  Part Revision Number", amc6821.getPartRevision());

  Serial.println();

  p_("---- Config register 1", amc6821.getConfig(1));
  b_("         Start Monitor", amc6821.getStartMonitor());
  b_("     Global Int Enable", amc6821.getGlobalIntEnable());
  b_("        RPM Int Enable", amc6821.getRPMIntEnable());
  b_("            PWM Invert", amc6821.getPWMInvert());
  b_("  Fan Fault Pin Enable", amc6821.getFanFaultPinEnable());
  // ---
  Serial.print("      Fan Control Mode = ");
  amc6821_conf1_fdrc_t my_fdrc = amc6821.getFanControlMode();
  switch (my_fdrc) {
    case AMC6821_CONF1_FDRC_AUTO_REMOTE: Serial.println("AUTO_REMOTE"); break;
    case AMC6821_CONF1_FDRC_MAX_SPEED: Serial.println("MAX_SPEED"); break;
    case AMC6821_CONF1_FDRC_SOFTWARE_DCY: Serial.println("SOFTWARE_DCY"); break;
    case AMC6821_CONF1_FDRC_SOFTWARE_RPM: Serial.println("SOFTWARE_RPM"); break;
    default: Serial.println("Unknown!");
  }
  // ---
  b_("      Therm Int Enable", amc6821.getThermIntEnable());

  p_("---- Config register 2", amc6821.getConfig(2));
  b_("        PWM Out Enable", amc6821.getPWMOutEnable());
  b_("             Tach Mode", amc6821.getTachMode());
  b_("           Tach Enable", amc6821.getTachEnable());
  b_("Remote Fail Int Enable", amc6821.getRemoteFailureIntEnable());
  b_("         LT Int Enable", amc6821.getLTIntEnable());
  b_("         RT Int Enable", amc6821.getRTIntEnable());
  b_("       LPSV Int Enable", amc6821.getLPSVIntEnable());

  p_("---- Config register 3", amc6821.getConfig(3));
  b_("       Term Fan Enable", amc6821.getTermFanEnable());

  p_("---- Config register 4", amc6821.getConfig(4));
  b_("            OVR Enable", amc6821.getOVREnable());
  b_("     Tach Reading Fast", amc6821.getTachReadingFast());
  b_("          Pulse Number", amc6821.getPulseNumber());

  Serial.println();

  p_("---- Status register 1", amc6821.getStatus(1));
  b_("              Fan Fast", amc6821.getFanFast());
  b_("              Fan Slow", amc6821.getFanSlow());
  b_("      Remote Temp High", amc6821.getRTHigh());
  b_("       Remote Temp Low", amc6821.getRTLow());
  b_("Remote Temp Over Therm", amc6821.getRTOverTherm());
  b_("   Remote Temp Failure", amc6821.getRTFailure());
  b_("       Local Temp High", amc6821.getLTHigh());
  b_("        Local Temp Low", amc6821.getLTLow());

  p_("---- Status register 2", amc6821.getStatus(2));
  b_("Remote T Over Critical", amc6821.getRTOverCritical());
  b_(" Local T Over Critical", amc6821.getLTOverCritical());
  b_("Local Temp Below Therm", amc6821.getLTBelowTherm());
  b_(" Local Temp Over Therm", amc6821.getLTOverTherm());
  b_("            OVR Enable", amc6821.getThermInput());

  /* ---------------------------------------------------------------------- */

  Serial.println();

  p_("T Fractions 0bRRR__LLL", amc6821.read(AMC6821_REG_TEMP_LBYTE), "**");

  p_("     Local Temperature", amc6821.getLocalTemp(), "°C");
  i = amc6821.getLocalMilliTemp();
  Serial.print("                                             ");
  Serial.print((float)i/1000);
  Serial.println(" °C");

  p_("    Remote Temperature", amc6821.getRemoteTemp(), "°C");
  i = amc6821.getRemoteMilliTemp();
  Serial.print("                                             ");
  Serial.print((float)i/1000);
  Serial.println(" °C");

  p_(" Local High Temp Limit", amc6821.getLocalHighTempLimit(), "°C");
  p_("  Local Low Temp Limit", amc6821.getLocalLowTempLimit(), "°C");
  p_("     Local Therm Limit", amc6821.getLocalThermLimit(), "°C");
  p_("Remote High Temp Limit", amc6821.getRemoteHighTempLimit(), "°C");
  p_("  RemoteLow Temp Limit", amc6821.getRemoteLowTempLimit(), "°C");
  p_("    Remote Therm Limit", amc6821.getRemoteThermLimit(), "°C");
  p_("   Local Critical Temp", amc6821.getLocalCriticalTemp(), "°C");
  p_("  Passive Cooling Temp", amc6821.getPassiveCoolingTemp(), "°C");
  p_("  Remote Critical Temp", amc6821.getRemoteCriticalTemp(), "°C");

  Serial.println();

  p_("   Fan Characteristics", amc6821.getFanCharacteristics());
  p_("   Duty Cycle Low Temp", amc6821.getDutyCycleLowTemp());
  p_("            Duty Cycle", amc6821.getDutyCycle());
  p_("       Duty Cycle Ramp", amc6821.getDutyCycleRamp());
  p_("Local Temp Fan Control", amc6821.getLocalTempFanControl());
  p_("  Remote T Fan Control", amc6821.getRemoteTempFanControl());

  Serial.println();

  q_("             Tach Data", amc6821.getTachData());
  n_("             Tach Data", amc6821.getTachDataRPM(), "RPM");
  q_("        Tach Low Limit", amc6821.getTachLowLimit());
  n_("        Tach Low Limit", amc6821.getTachLowLimitRPM(), "RPM");
  q_("       Tach High Limit", amc6821.getTachHighLimit());
  n_("       Tach High Limit", amc6821.getTachHighLimitRPM(), "RPM");
  q_("          Tach Setting", amc6821.getTachSetting());
  n_("          Tach Setting", amc6821.getTachSettingRPM(), "RPM");

  Serial.println("------------------------------------------------------------\n");
  delay(1000);
  if (looplimit <= 0) { while (1) delay(19000); } else { looplimit--; }
}

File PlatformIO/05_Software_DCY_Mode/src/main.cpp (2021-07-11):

#include <Arduino.h>
#include <SPI.h>
#include <Wire.h>
#include <Tecsmith_AMC6821.h>

#ifdef ARDUINO_ESP8266_ESP01
  #define SDA_PIN 0
  #define SCL_PIN 2
#endif

/**
 * ## Software DCY Control Mode
 *
 * When the bits [FDRC1:FDRC0] = [00], the fan works in the software DCY
 * control mode. The host writes the desired duty cycle value corresponding
 * to the required RPM into the DCY register. The duty cycle changes to the
 * new value immediately after the writing. In this mode, if the TACH
 * measurement is enabled (bit 2 of 0x01 = 1) and the TACH-MODE bit (bit 1 of
 * 0x01) is cleared ('0'), the duty cycle from the PWM-OUT pin is forced to 0%
 * when the value in the DCY register is less than 7%. However, if the TACH
 * measurement is disabled (bit 2 of 0x01 is cleared) or the TACH mode is set
 * ('1'), the DCY register always keeps the programmed value written by the
 * host and is not forced to '0' even when the programmed value is less than
 * 7%.
*/

Tecsmith_AMC6821 amc6821;  // instance
String command;  // interact with Serial

void __b(uint8_t addr, const char * pre = "") {
  Serial.print(pre);  Serial.print(" ");
  uint8_t v = amc6821.read(addr);
  for (int x = 7; x >= 0; x--) { Serial.print(bitRead(v, x)); }
  Serial.print(" 0x");
  if (v < 16) { Serial.print("0"); }  Serial.println(v, 16);
}

void showPrompt() {
  Serial.println();
  __b(AMC6821_REG_CONF1, "c1");
  __b(AMC6821_REG_CONF2, "c2");
  __b(AMC6821_REG_CONF3, "c3");
  __b(AMC6821_REG_CONF4, "c4");
  __b(AMC6821_REG_STAT1, "s1");
  __b(AMC6821_REG_STAT2, "s2");
  __b(AMC6821_REG_DCY, "dc");
  Serial.println("\nType Command (hello, local, remote, show, 10 .. 100, help)");
  Serial.print("> ");
}

void showHelp() {
  Serial.println("\nCommands available:\n");
  Serial.println("  hello / H  - prints \"Hello World\" (used for testing serial interface)");
  Serial.println("  local / L  - show local temperature");
  Serial.println("  remote / R - show remote temperature");
  Serial.println("  show / S   - show duty cycel");
  Serial.println("  0          - 0% duty cycle");
  Serial.println("  10 / 1     - 10% duty cycle");
  Serial.println("  20 / 2     - 20% duty cycle");
  Serial.println("  30 / 3     - 30% duty cycle");
  Serial.println("  40 / 4     - 40% duty cycle");
  Serial.println("  50 / 5     - 50% duty cycle");
  Serial.println("  60 / 6     - 60% duty cycle");
  Serial.println("  70 / 7     - 70% duty cycle");
  Serial.println("  80 / 8     - 80% duty cycle");
  Serial.println("  90 / 9     - 90% duty cycle");
  Serial.println("  full / F   - 100% duty cycle");
  // Serial.println("");
  // Serial.println("");
}

void _setDCY(unsigned int percentage) {
  int p = amc6821.getDutyCycleP();
  Serial.print("Duty Cycle was ");
  Serial.print(p);
  Serial.println("%");

  amc6821.setDutyCycleP(percentage);
  Serial.print("Duty Cycle setting to ");
  Serial.print( percentage );
  Serial.println("%");

  delay(500);

  p = amc6821.getDutyCycleP();
  Serial.print("Duty Cycle is now at ");
  Serial.print(p);
  Serial.println("%");
}

// ---------- ! ----------

void setup() {
  // put your setup code here, to run once:

  Serial.begin(57600);
  while (!Serial) delay(10);

  #ifdef ARDUINO_ESP8266_ESP01
  Wire.begin(SDA_PIN, SCL_PIN);
  #else
  Wire.begin();
  #endif

  Serial.println("\n\n--------------------------------------------");
  Serial.println("Tecsmith_AMC6821 - Software DCY mode example");
  Serial.println("--------------------------------------------\n");

  // Try to initialize!
  if (!amc6821.begin( AMC6821_CONF1_FDRC_SOFTWARE_DCY )) {
    Serial.println("Failed to find AMC6821 chip");
    while (1) { delay(10); }
  }
  // amc6821.setDutyCycle(191);  // 75% DYC
  amc6821.setTachMode(false);
  amc6821.setPWMOutEnable(true);
  Serial.println("AMC6821 Found!");

  delay(2000);  // pause a bit

  Serial.print( amc6821.getFanControlMode() );

  amc6821.start();

  showPrompt();
}

void loop() {
  // put your main code here, to run repeatedly:

  if (Serial.available()) {
    command = Serial.readStringUntil('\n');
    command.trim();
    command.toLowerCase();

    if (command.equals("h") || command.equals("hello")) {
      Serial.println("Hello World");
    }

    else if (command.equals("?") || command.equals("help")) {
      showHelp();
    }

    else if (command.equals("l") || command.equals("local")) {
      float t = amc6821.getLocalMilliTemp() / 1000;
      Serial.print("Local temp = ");
      Serial.print( t );
      Serial.print("°C / ");
      Serial.print( Tecsmith_AMC6821::toFahrenheit(t) );
      Serial.println("°F");
    }

    else if (command.equals("r") || command.equals("remote")) {
      float t = amc6821.getRemoteMilliTemp() / 1000;
      Serial.print("Remote temp = ");
      Serial.print( t );
      Serial.print("°C / ");
      Serial.print( Tecsmith_AMC6821::toFahrenheit(t) );
      Serial.println("°F");
    }

    else if (command.equals("s") || command.equals("show")) {
      int p = amc6821.getDutyCycleP();
      Serial.print("Duty Cycle is ");
      Serial.print(p);
      Serial.println("%");
    }

    else if (command.equals("0")) { _setDCY(0); }
    else if (command.equals("1") || command.equals("10")) { _setDCY(10); }
    else if (command.equals("2") || command.equals("20")) { _setDCY(20); }
    else if (command.equals("3") || command.equals("30")) { _setDCY(30); }
    else if (command.equals("4") || command.equals("40")) { _setDCY(40); }
    else if (command.equals("5") || command.equals("50")) { _setDCY(50); }
    else if (command.equals("6") || command.equals("60")) { _setDCY(60); }
    else if (command.equals("7") || command.equals("70")) { _setDCY(70); }
    else if (command.equals("8") || command.equals("80")) { _setDCY(80); }
    else if (command.equals("9") || command.equals("90")) { _setDCY(90); }
    else if (command.equals("f") || command.equals("full") || command.equals("100")) { _setDCY(100); }

    else if (command.equals("q") || command.equals("quit") || command.equals("bye")) {
      Serial.println("Can't quit, I'm an MCU");
    }
    else {
      Serial.print("Unknown command: ");
      command.toUpperCase();
      Serial.println(command);
    }

    showPrompt();
  }
  delay(1);
}

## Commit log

2013-06-04 initial upload
    [arduino_footprint.brd, av_unit_fan_ctrl.brd, av_unit_fan_ctrl.sch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]
2021-07-11 re-upload of v2.0
    [BOM_amc6821-breakout-v2.0.xlsx, BOM_esp-01-qwiic-devbrd-v1.0.xlsx, PnP_amc6821-breakout-v2.0_front.xlsx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]
2021-07-11 re-upload of v2.3
    [BOM_amc6821-breakout-v2.0.xlsx, BOM_amc6821-breakout-v2.3.xlsx, BOM_esp-01-qwiic-devbrd-v1.0.xlsx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]
2021-07-11 clean up of v2.3
    [amc6821-breakout-v2.2.brd, amc6821-breakout-v2.2.sch, amc6821-breakout-v2.3.brd]
2021-07-18 remove v2.3 files
    [BOM_amc6821-breakout-v2.3.xlsx, PnP_amc6821-breakout-v2.3_front.xlsx, amc6821-breakout-v3.0.brd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]
2021-07-18 v3 upload - split into 2 boards
    [amc6821-breakout-v3.0.brd, fan-host-board-v1.0.brd, fan-host-board-v1.0.sch]
2021-07-19 fixes to the TACH lines
    [fan-host-board-v1.0.brd, fan-host-board-v1.0.sch]
2021-07-19 move C3 closer to the IC
    [amc6821-breakout-v3.0.brd, amc6821-breakout-v3.0.sch]
2021-07-19 minor rename, JP4
    [amc6821-breakout-v3.0.brd, amc6821-breakout-v3.0.sch]
2021-07-20 minor edits
    [amc6821-breakout-v3.0.brd, fan-host-board-v1.0.brd, fan-host-board-v1.0.sch]
2021-09-18 rounded corners
    [amc6821-breakout-v3.0.brd, amc6821-breakout-v3.0.sch]
2021-09-24 added LED interface
    [fan-interface-v1.0.brd, fan-interface-v1.0.sch]
2021-10-12 added active buzzer
    [fan-host-board-v1.0.brd, fan-host-board-v1.0.sch, fan-interface-v1.0.brd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]

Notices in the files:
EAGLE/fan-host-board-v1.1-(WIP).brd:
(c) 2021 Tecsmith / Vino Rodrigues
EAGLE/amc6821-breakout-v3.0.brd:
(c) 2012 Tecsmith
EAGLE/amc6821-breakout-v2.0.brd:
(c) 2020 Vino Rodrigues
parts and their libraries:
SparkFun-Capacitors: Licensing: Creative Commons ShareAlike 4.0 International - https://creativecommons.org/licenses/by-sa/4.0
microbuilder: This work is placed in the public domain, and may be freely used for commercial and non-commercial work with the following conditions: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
